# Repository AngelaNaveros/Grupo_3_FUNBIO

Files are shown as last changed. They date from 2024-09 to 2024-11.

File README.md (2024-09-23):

# FUNDAMENTOS DE BIODISENO GRUPO 3

## Descripción del curso 
> Este curso nos enseña a aplicar principios de diseño, biología e ingeniería para desarrollar **soluciones innovadoras** a problemas clínicos. Utilizando un enfoque de aprendizaje basado en proyectos, trabajaremos en **equipos** multidisciplinarios para identificar **necesidades clínicas no satisfechas**, generar ideas y crear prototipos rápidos que puedan validarse en entornos reales. A través de la **investigación de campo, el prototipado iterativo y la retroalimentación de expertos,**  adquiriremos habilidades en innovación en salud, pensamiento de diseño y validación de productos.
>
## Miembros del equipo 3

* ### **Angela Naveros Diaz**
> <p align="center" >
>
> Estudiante de Ingeniería Biomédica. Cursando 4 Ciclo. Planeo especializarme en Ing. Clínica y realizar investigaciones para apoyar al entorno con inovaciones en dispositivos médicos o facilitando el trabajo del mismo entorno.
>
> ### **Rol: Coordinador general**
> Me encargo de promover la colaboración y motivar al equipo para que se cumplan los objetivos planteados, además me encargo de subir el material al portal de GitHub.
  
* ### **Astrid Mejía Barreto**
> <p align="center" >
>
> Alumna de Ingeniería Biomédica con interés en Señales e Imágenes y Tejidos y biomateriales 
>
> ### **Rol: Coordinador de Diseño 3D** 
> Encargada de bocetar el diseño del prototipo en diferentes perspectivas y modelar digitalmente la propuesta con un software de diseño en tres dimensiones.
  
* ### **Mael Chaupis**
> <p align="center" >                    
>
> Estudiante de la carerra de ingeniería biomédica de la Pontificia Universidad Católica del Perú y Universidad Peruana Cayetano Heredia. Estoy cursando Fundamentos de Biodiseño.
>
> ### **Rol: Diseño Electrónico**
> Estoy interesado en la rama de Biomecánica y Rehabilitación.

* ### **Alexander Huamanvilca**
> <p align="center" >       
>
> Estudiante de Ing. Biomédica y me encuentro en cuarto ciclo, decidí estudiar esta carrera por varios motivos, entre ellos, la recomendación de algunos familiares, el concepto de aplicaciones de la ingeniería en el campo de la salud, logrando llamar mi atención por completo.
>
> ### **Rol: Protootipado electrónico**
> Mi rol durante el curso es el prototipado electrónico, me encargaré de la parte electrónica, acoplándome a las necesidades del equipo, verificando también, el funcionamiento del proyecto. Aprendiendo y trabajando junto con el programador para asegurar la calidad del proyecto.

* ### **Solangel Macedo Pereira**
> <p align="center" >
> 
> Alumna de Ingenieria Biomédica en 4to ciclo con rama de interés en Ingeniería de Tejidos y Biomateriales asi como Biomecánica y Rehabilitación 
> 
> ### **Rol: Manufactura Digital**
> Responsable del uso de teconologias como modelado 3D y simulaciones para la correcta fabricación del producto

## Análisis del caso
> 
> ### Caso Clínico
> La paciente es una mujer de 45 años. Sus sintomas iniciales fueron sensaciones anormales como hormigueo (parestesias) y pérdida de la función muscular. Fue diagnosticada en el año 2023 de NMO (Neumoremieltisis óptica), una enfermedad autoinminetarai que causa daño en el nervio óptico y la médula espinal a tráves de inflamación.De acuerdo a su examen físico, presenta sensibilidad hasta el ombligo, en los miembros inferiores tiene hipoestesia e hipoalgesia, en si no puede realizar marcha. Aunque presenta movimiento voluntario en los tobillos no vence la gravedad. Asimismo presenta complicaciones, úlcera por presión en la región sacra de 3X2 cm de grado III como el uso de pañal y sonda permanente. 

> ### Definición
> Las lesiones de médula espinal (LME), como su nombre lo indica, se refieren al daño causado en la médula espinal [1]; zona importante debido a su rol como medio de transporte de comunicación entre el cerebro con el cuerpo. Esta divido en 5 segmentos: cervical, torácico, lumbar, sacro y nervio coccígeas. Cada segmento se encarga de transmitir información específica como función motora o sensorial. Debido a esto, una lesión en esta zona llega a ser perjudicial para el paciente [2]. 

> ### Causas
> De acuerdo a la Organización Mundial de la Salud (OMS), cada año entre 250 500 y 500 000 personas son diagnosticadas de lesión medular. La causa más frecuente por las lesiones son traumatismo como caídas o accidentes de tránsito [1] aunque también existen lesiones no traumáticas causadas por enfermedades autoinmunes, trastornos genéticos, entre otros [3]. 

> ### Tipos
> Para determinar el tipo de lesión medular, clasificarlo de acuerdo al nivel neurológico y el alcanze de la lesión, se utiliza la escala de puntuación ASIA (American Spinal Injury Association), empleado globalmente.
> <p align="center" >
> 
> Figura 1: Escala ASIA [2]
> 
> De esta manera se realizan exámenes para identificar el nivel sensorial y función motora a través de diferentes ejercicios y pruebas; asi determinar si la lesión es incompleta (ASIA B, ASIA C, ASIA D Y ASIA E) cuando todavía existen funciones motoras y sensoriales en la región sacra, específicamente S4-S5; o completa (ASIA A), pérdida de esas funciones. [1], [2]. 

> ### Consecuencias
> Por otro lado, este tipo de lesiones causan cambios drásticos en la vida de los pacientes. Aparte de su reducida función motora y sensorial de acuerdo a la gravedad, sufren de complicaciones por su lesión. Llegan a sufrifr de una función vesical alterada, conocido como vejiga neurogénica debido al daño nervioso, el sintoma mas comun es la incontinencia. Por otro lado, las heridas por presión en la piel presentan otro riesgo más debido a la imposibilidad de realizar cambios de posición. Se estima que el 85% de pacientes con lesión medular han presentado alguna vez lesiones de presión, por ejemplo: UPP (úlceras por presión). Todas estas dificultades afectan las actividades diarias de los pacientes, poniendo en peligro su calidad de vida como su rol en la sociedad. [4]

>
> ### Tratamiento
> Es por ello la importancia de la rehabilitación cuyo objetivo es el retorno a una vida independiente y completa. Se necesita un equipo de profesionales especializados para el tratamiento en conjunto como también la participación del paciente. Freeman y Bender-Burnett [4] determinaron los siguientes cambios para cumplir la meta de recuperación.
> * Ajuste psicológico y social: Apoyo psicológico al paciente para aceptar su pérdida y nuevo rol en la sociedad.
> * Ajuste vocacional y profesional: Resulta no posible regresar al trabajo antes de la lesión por lo que se necesita cambio y adaptación0.
> * Independencia funcional: Adquisición de habilidades físicas para el cuidado personal y movilización propia en casa y afuera.
> * Adquisición de equipos médicos: Necesarios para mantener la salud del paciente así como mejorar su independencia.
> * Salud y bienestar: Seguimiento continuo para evitar secuelas secundarias como heridas por presión o infecciones.
> El enfoque es en la autonomía del paciente para que conozca las propias habilidades de su propio cuerpo, información de su lesión y confianza en si mismo. Así, se siente motivado a continuar su programa de rehabilitación y tomar iniciativa en su mejora.

> ### Contexto Nacional
>De acuerdo con datos del  INNEI [5] , 3 millones 51 mil 612 peruanos padecen de discapacidad, entre ellos, el 15%, 462 mil 062 tienen dificultad para moverse o caminar.
> Por otro lado, se tiene que tomar en cuenta el contexto socioeconómico y como este afecta en el tratamiento y rehabilitación en el paciente. En países desarrollados, existe el acceso a tecnologías, como terapias genéticas y técnicas de bioingeniería, que dan mejores resultados a comparación de países de Latinoamérica y el Caribe.
> En el Perú, no es solo el problema de la falta de tecnología sino también estructural, específicamente en el sistema de salud. La falta de organización y barreras politicas han impedido el acceso de recursos y centros de salud. Esto se ve en la mayor frecuencia de lesiones medulares no traumáticas causado por enfermedades autoinmunes, afecciones degenerativas, infecciones virales y bacterianas, entre otros. De acuero a un estudio en el Instituto Nacional de Rehabilitación de la cuidad del Callao, el 37.6% de las personas con ese tipo de lesión tenían una enfermedad infecciosa mientras que el 15.7% fueron por enfermedades degenerativas [3].
> Se necesita de una mejora del sistema actual de salud, enfocados en medidas preventivas con el objetivo de reducción de enfermedades que afectan el sistema neurológico y de esa manera se evita que progresen a lesiones de médula no traumáticas.

> <p align="center" >

## Diagrama de Ishikawa

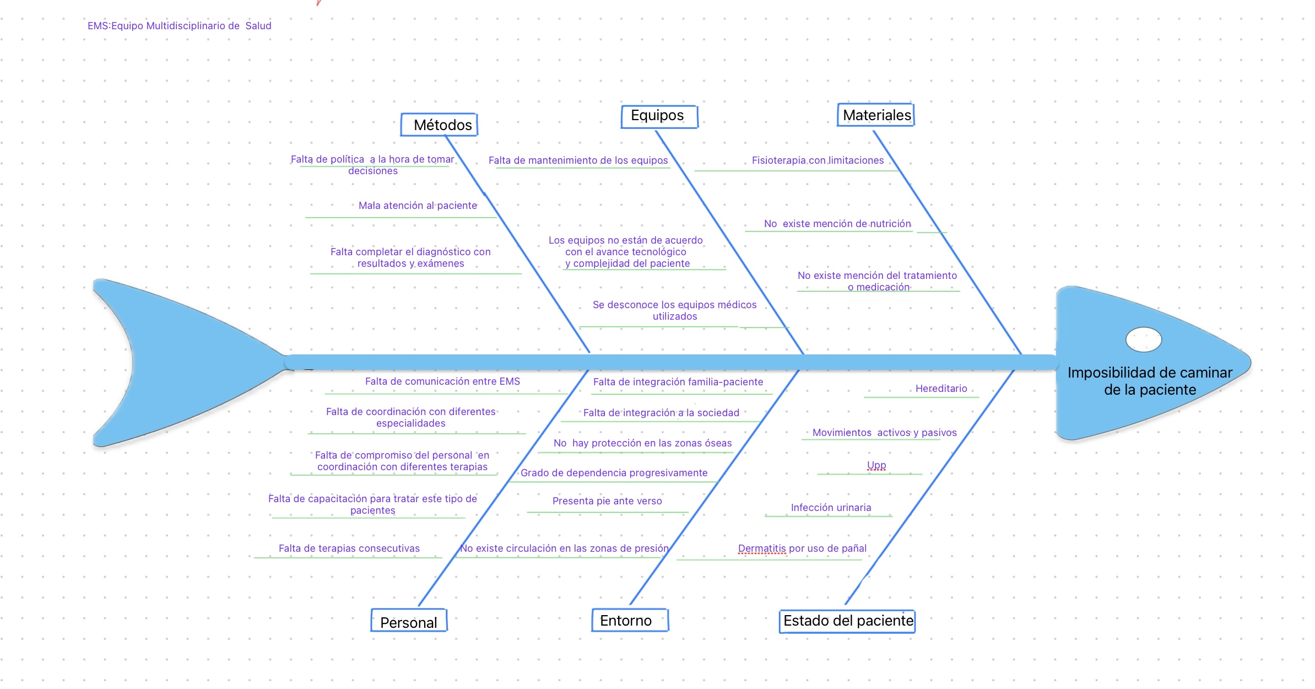
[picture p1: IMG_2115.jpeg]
> <p align="center" >

## Estado del arte
### Papers científicos
>
>  * #### Improving Walking Autonomy of People with Paraplegia wearing Powered Exoskeletons
>   Este estudio enfocado en la paraplejía, se propone el uso de exoesqueletos motorizados con un patrón de marcha que utiliza una postura inclinada para mover eficazmente el CoM hacia adelante en beneficio de la autonomía de las personas. Esta idea se dio tratando de aprovechar la diferencia de altura entre la pierna que queda delante al caminar y la que queda atrás. Presentan que los pacientes tienen dificultades para controlar el centro de masa (CoM) de su cuerpo debido a la falta de movimiento en las piernas o la cintura. Estos exoesqueletos motorizados, que son dispositivos de asistencia para las extremidades inferiores, han sido desarrollados para ayudarles a caminar nuevamente, pero tienen grados de libertad limitados y no pueden controlar completamente el CoM sin la ayuda de terapeutas físicos.
> <p align="center" > 

> * #### OMNIBOT: Un sistema de movilidad verticalizada robótica para personas con discapacidad
>   En el artículo se analiza dispositivos para que los pacientes puedan pasar de una forma sentada a una erguida, detallando las diferencias entre dispositivos de rehabilitación y dispositivos de movimiento. Proponen al dispositivo OMNIBOT el cual permite un movimiento lateral y rotacional gracias a sus ruedas Mechanum, y facilita la transición entre posiciones sentada y erguida. Este dispositivo incluye tecnología de aprendizaje automático, monitoreo biométrico, y opciones de personalización. Es adecuado para espacios interiores estrechos y no puede superar obstáculos o escaleras sin una rampa. Además señalan que existe una competencia que es TEK RMD, pero este tiene limitaciones en maniobrabilidad en espacios reducidos y accesibilidad debido a su tamaño.
> <p align="center" >
  
>  * #### Cognitive-Chair: AI based advanced Brain Sensing Wheelchair for Paraplegic/Quadriplegic people">
>
>    Este artículo presenta un sistema para el control de sillas de ruedas mediante una banda colocada en la cabeza del paciente, que utiliza señales neuronales o ondas cerebrales mediante tecnologías como ***Interfaces Cerebro-Computadora (BCI), Electrooculografía (EOG) y Electroencefalografía (EEG)***. Este sistema incorpora características de seguridad y movilidad inteligente. Además incluye funciones avanzadas como detección de caídas, capacidad para atravesar espacios estrechos y conducción autónoma. Al aplicar estas tecnologías a un modelo pequeño de silla de ruedas, se logró una precisión notable en la detección de señales neuronales. 
> <p align="center" >
>
### Ensayos clínicos

>  * #### El diseño de un ensayo de control aleatorio de caminar asistido por exoesqueleto en el hogar y la comunidad sobre la calidad de vida en personas con lesión crónica de la médula espinal
>   Ensayo clínico de dos grupos, no ciego, aleatorizado y controlado. El grupo de intervención consiste en el estándar de atención más la caminata asistida por exoesqueleto
El grupo control consiste en el estándar de atención, esto se define como el uso de una silla de ruedas para la movilidad.
El estudio tiene tres fases: Detección, orientación o formación e intervención 
Los veteranos masculinos o femeninos o el personal militar en servicio activo con SCI traumático o no traumático de duración de ≥6 meses, que tienen ≥18 años de edad, médicamente estables y usan una silla de ruedas para la movilidad en interiores y exteriores, son elegibles para la detección
La inscripción objetivo es de 160 participantes que serán aleatorizados y asignados al grupo de intervención (n = 80) o al grupo de control (n = 80)
Los resultados obtenidos durante este estudio se traducirán rápidamente a la atención clínica. El objetivo a largo plazo es compartir los datos de este estudio con el personal clínico para informar los procedimientos de capacitación y el desarrollo de pautas para la prescripción clínica del dispositivo EAW para uso en el hogar/comunitario en veteranos con SCI. Esto está sucediendo actualmente a través de interacciones continuas entre el personal de investigación y clínico.

>  * #### Apósitos de espuma multicapa adhesivo de silicona para prevenir úlceras por presión sacro adquiridas en el hospital: una evaluación económica basada en un ensayo controlado aleatorio pragmático financiado con fondos públicos vinculado a datos del mundo real
>   Tiene como objetivo estimar la rentabilidad de los apósitos de espuma de silicona multicapa sacro como terapia profiláctica adyuvante en comparación con la prevención estándar de las UPP
El grupo aleatorio es de 1633 pacientes (edad media 80 ± 12 años, el 57,6 % de las mujeres) de los cuales 1601 con intención de tratar compararon UPP en el sacro. 
El grupo de tratamiento con los apósitos multicapa de silicona (n=1062) y grupo de atención estándar (n=539)
Se observaron úlceras por presión en el sacro en el 2,8 % (30/1062, IC del 95 % 1,8-3,8 %) y el 4,8 % (26/539, IC del 95 % 3,0-6,6%) de los pacientes del grupo de tratamiento y grupo de atención estándar. El riesgo de desarrollar una nueva úlcera por presión en el sacro se redujo estadísticamente significativamente en un 41 % en el grupo de tratamiento
Conclusión: El uso preventivo de apósitos de espuma multicapa adhesiva de silicona en el sacro para una población similar a la población de ensayo pragmático puede ser apoyado tanto desde un punto de vista clínico como económico.

## Bibliografia

[1]    Actualización sobre la situación de la lesión medular en América Latina: retos y oportunidades en su atención        | Revista Colombiana de Medicina Física y Rehabilitación. (s. f.). https://revistacmfr.org/index.php/rcmfr/article/view/360/414#content/citation_reference_3 

[2]    Patek, M., & Stewart, M. (2023). Spinal cord injury. Anaesthesia & Intensive Care Medicine, 24(7), 406–411. https://doi.org/10.1016/j.mpaic.2023.04.006 

[3]    Almubaslat, F., Sanchez-Boluarte, S. S., & Diaz, M. M. (2023). A review of neurological health disparities in Peru. Frontiers in Public Health, 11, 1210238. https://doi.org/10.3389/fpubh.2023.1210238 

[4]    Somers, M., & Bender-Burnett, J. (2024). Spinal cord injury: Functional rehabilitation. F.A. Davis.

[5]    Censos Nacionales 2017: XII de Población, VII de Vivienda y III de Comunidades Indígenas. (n.d.). https://www.inei.gob.pe/media/MenuRecursivo/publicaciones_digitales/Est/Lib1539/libro.pdf 

[6]  Acta neurológica colombiana.  vol.39 no.1 Bogotá Jan./Mar. 2023  Epub Apr 05, 2023
“Evolución clínica en neuromielitis óptica comparando el manejo con azatioprina o rituximab”
http://www.scielo.org.co/scielo.php?script=sci_arttext&pid=S0120-87482023000100006&lang=es

[7] Granados Carrera, J. C. (2020). Efecto de la rehabilitación en la calidad de vida de personas con lesión medular. Anales de la Facultad de Medicina (Lima, Peru : 1990), 81(1), 6–13. https://doi.org/10.15381/anales.v81i1.16852

[8] Zeca Sanca, B., Coll Costa, J. de L., Rodríguez García, A. R., Sentmanat Belison, A., & Ramos Quian, Y. (2023). Impacto de los ejercicios físicos en la rehabilitación de pacientes con lesiones medulares cervical incompleta, en Guinea-Bissau. Podium, 18(1). http://scielo.sld.cu/scielo.php?pid=S1996-24522023000100007&script=sci_arttext

[9] Angustias, T. A. M. (s. f.). Medidas preventivas para evitar complicaciones de salud derivadas del uso de sondajes vesicales en pacientes lesionados medulares. https://scielo.isciii.es/scielo.php?pid=S1695-61412013000200018&script=sci_arttext

[10] Paulina, S. B., Tomás, G. L., Sara, V. T., Isabella, T. C., Natalia, R. V., Restrepo, C. A., Zuluaga, M., I., Paulina, S. B., Tomás, G. L., Sara, V. T., Isabella, T. C., Natalia, R. V., Restrepo, C. A., & Zuluaga, M., I. (s. f.). Evolución clínica en neuromielitis óptica comparando el manejo con azatioprina o rituximab. www.scielo.org.co. https://doi.org/10.22379/24224022436

* ##### **THX Valeria Ccoa**

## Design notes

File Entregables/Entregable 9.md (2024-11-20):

# Verificación de Diseño (Software)
<p align="center">

# Verificación de Diseño (Hadware)
> ## Preguntas clave
> * **¿Cuanto es el tiempo que debe durar la batería de forma autónoma?**
>
>     La batería debería ser capaz de durar una semana completa, día y noche, mínimo. Sin embargo, para el prototipado, buscamos que dure un lapso de 3h mínimo, para demostrar la eficiencia en la rotación del colchón.
> 
> * **¿El dispositivo es independiente?**
>
>     Por el momento la energía del circuito depende de la conexión del arduino con la computadora, sin embargo se está trabajando en la conexión con la batería.
>   
> * **¿El peso del dispositivo no supera los 5 kg?**
>
>     Se busca que la caja con todos los componentes sea lo más liviana posible para que sea de fácil transporte. Esto se puede lograr con la mejora continua de cada componente, luego de evaluado el sistema integro del sistema.
>   
> * **¿Cuántos botones físicos debe tener el dispositivo para su funcionamiento?**
>
>     Solo sería necesario de un botón fisico, para encendido y apagado del circuito.
>   
> * **¿El dispositivo es cómodo para el paciente?**
>
>     Lo único que tiene contacto con el paciente es el colchón, el cúal será elaborado con silicona genérica para el prototipo, con idea de cambiar este por el material de lona inflable.
>   
> * **¿Cuál es la inclinación necesaria que debe realizar el colchón para que el paciente pueda realizar la rotación lateral sin esfuerzo?**
>
>     La inclinación depende de la masa del paciente, pero en términos generales se recomienda una inclinación mayor a 30°.
>
>  <p align="center">

# Verificacion de Diseño (Diseño de 3D)
<p align="center">

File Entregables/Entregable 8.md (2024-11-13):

# Integración Hadware - Software - Manufactura Digital

## Introducción y Contextualización del Prototipo
> El prototipo consiste en un dispositivo cuya funcionalidad sirve de asistencia a la hora de realizar cambios posturales, a través de un sistema neumático y electrónico, y de esta manera prevenir la aparición de UPP (Ulceras por presión). De acuerdo a un estudio del Hospital de Lima [1], de 256 pacientes hospitalizados el 19,5% presento UPP en su estadía  siendo la zona más afectada la zona sacra (76%). Las UPP resultan un problema común en pacientes inmovilizados, especialmente con lesiones medulares. La falta de movimiento genera presión constante en áreas vulnerables, como oseas, zona sacra y talones, por lo que el personal de salud tiene que realizar cambios posturales cada 2 a 3 horas. Sin embargo la falta de recurso económicos y personal afecta el cuidado y tratamiento en la rehabilitación de los pacientes. Por lo que el prototipo brinda la solución con el problema de recursos sino que también ofrece la oportunidad de autonomía al paciente ya que el dispositivo le dara la capacidad de ser un participante activo en su tratamiento, este será capaza de realizar los cambios posturales por su cuenta gracias al apoyo que el prototipo brinda.  
>
> Para la fase de integración al armado del prototipo se espera que el sistemático neumatico y electronico funcionen correctamente por separado así mismo en la hora de unión de estos para el inflado y desinflado a control del colchón. 
>

## Componentes del Prototipo
> * **Lista de componentes principales:**
>    - Válvulas de 4 entradas: 
>    - Válvulas para servomotor:
>    - Tubos de latex de 6mm de diametro interior:
> * **Interacción entre componentes:**
>
>     La **válvula de 4 entradas** se conecta a la máquina de llenado al vacío mediante los **tubos de látex**, con un pedazo de estos tubos conectado a la máquina que luego convergen en 3 sistemas diferentes donde conectan a las **válvulas para servomotor** para inflar de forma independiente cada sector del colchón. En estas válvulas para servomotor, se coloca una manguera para llenado, que es la que continua desde la máquina de llenado al vacío y la otra manguera que se une del colchón y tiene salida al exterior, para permitir que el colchón se desinfle.
>   
> * **Diagrama de integración:**
><p align="center">

## Proceso de Integración
> * **Plan de Integración**
>    Como requerimos que las válvulas dejen o no, pasar el aire hacia los cojines. Implementaremos servo motores para negar y aceptar el pase del aire, luego aquello que de las órdenes será un módulo bluetooth  para mandar las señales hacia un microprocesador. En este caso este microprocesador será Arduino UNO, es mediante su programación que haremos que nuestro sistema funcione. Para unir los componentes necesitaremos un protoboard y cables jumper.
>
> * **Pruebas Intermedias:**
>  1. Primero es necesario conocer las conexiones y verificar si funcionan con el arduino UNO.
>     <p align="center">
>  2. Después de entender cómo funcionan los servos , verificaremos la disponibilidad y uso del módulo bluetooth.
>     <p align="center">
>  3. Finalmente, después de lograr entablar una relación entre el módulo bluetooth y los servos, los integramos físicamente en un mismo sistema(Integramos solo un servo en la imagen para garantizar un primer uso eficiente).
>     <p align="center">

> * **Objetivos Específicos:**
>    - La idea es poder dar órdenes de movimiento a los servomotores mediante comandos o una aplicación externa conectada al módulo bluetooth, obviamente todo ello controlado mediante programación Arduino.
>      
> * **Desafíos y ajustes realizados:**
>   - Problemas encontrados:
>       * Al inicio del modulo bluetooth pasaba el primer paso con *“Verify”* pero cuando tocaba  probar el *upload* mandaba mensajes de error. No reconocía al módulo. Sin embargo, luego de probar de diferentes formas el código, desconectando los pines de transmisión de datos y recepcionando datos(TXD Y RXD) y dandole inciar al “veriffy”  y seguido el “upload”. Una vez funcionó sin conectar los pines. Se definieron nuevos pines para que cumplan las funciones de TXD Y RXD(eran normalmente 0 y 1, pero se cambiaron por 2 y 3).
>
>       <p align="center">
>       Mi resultado fue que termino por funcionar con un codigo diferente  y no me figuraba ningun mensaje de error.
> <p align="center">
>        
>         Se decidió probar el Serial monitor con la app de mi celular “ Arduino bluetooth controller”
> <p align="center">
>        
>         El servo uno responde a lo siguiente: realiza un giro de 180 grados en sentido antihorario  cuando sale la letra “a”, y da un giro (con el mismo angulo) pero en sentido horario al momento de  salir la letra  “j” (esto es para un solo servo).
><p align="center">
>
> 
> * **Revisión de compatibilidad y sincronización:**
>  
> (esto es ya comprobando los 3 servos)
>
>  mando el mensaje desde mi celular 
><p align="center">
> 
> para este caso definimos lo siguiente:
> 
> - servo 1 :giro 180 grados  sentido antihorario  al recibir la señal de la  letra “a” y sentido  horario  con el mismo giro para la letra  “j”
> 
> - servo 2: giro antihorario(180 grados ) con la letra “s” y  giro horario (mismo 180 °) con la letra “k”
> 
> - servo 3 : giro antihorario(180 °) con la letra “d” y giro horario ( mismo  180°) con la letra “l” y lo recibi y figura en mi serial monitor del codigo arduino 
><p align="center">

## Pruebas y Verificación
>
> 1. Primero necesitamos verificar que los servomotores funcionen de manera alterna para así verificar su funcionamiento. Para verificar las conexiones y su funcionamiento , utilizaremos tanto el IDE Arduino y Tinkercad para comprobar que funcionen correctamente bajo código.
> <p align="center">
>
> 2. Ahora verificaremos que el módulo bluetooth funcione correctamente y nos bote señal y  de esa manera verificar que los servos nos reciban las órdenes..
>
> <p align="center">
> 
> * **Resultados y pruebas:**
>   - La idea de las pruebas era verificar que el circuito sea un mismo sistema y que cada componente esté relacionado al otro.
>   - Gracias a las pruebas nos dimos cuenta que era más factible un módulo bluetooth que un sensor IR, debido a la diferencia de facilidad de obtención de señal.
>   - De igual forma, gracias a las pruebas físicas nos dimos cuenta sobre limitaciones con el código en IDE Arduino, ya que únicamente con Tinkercad, no aseguraba el 100% del funcionamiento del circuito y/o sistema.
>
> * **Resultados y pruebas:**
>   -  Como bien vimos en las pruebas, el Arduino es capaz de recibir los mensajes desde un dispositivo móvil mediante el módulo bluetooth. Por lo que, gracias a esta aplicación, el enviar mensajes para activación o desactivación de los servos es factible.
>   - Como los servos son capaces de recibir las órdenes del Arduino, su movimiento será el que logre que las válvulas se abran o se cierren, lo que permitiría el funcionamiento de la misión principal.

## Conclusiones y Próximos Pasos
> * **Resumen de logros:**
>   - Se logró la aprobación del circuito electrónico, garantizando su funcionamiento bajo las condiciones de operación establecidas. Se han culminado exitosamente las pruebas del mecanismo.
>   - Se aprobaron las ediciones finales en el modelado 3D y se pasa a llenar la solicitud de impresión 3D en el laboratorio físico.
>   - Por el momento, se buscan alternativas de fabricación para el colchón, teniendo como opciones la impresion en negativo y utilizar silicona o fabricarlo con material de lona inflable). En el transcurso de la semana se realizarán pruebas de fabricación que posteriormente serán enviadas para la debida aprobación y continuando con su fabricación.
>   - Una vez se tengan impresas las piezas de prueba y el colchón fabricado, se realizarán las debidas pruebas, integrando el mecanismo con la manufactura 3D para ver el correcto funcionamiento del prototipo.
> * **Aspectos por mejorar:**
>   - La falta de pruebas en las mangueras neumáticas junto con las piezas de impresión 3D presentan un riesgo para el cumplimiento de los plazos de entrega. Cualquier ajuste al modelado 3D podría generar retrasos significativos
persiste el problema de los métodos de fabricación para el colchón.
>   - Aún no se tiene un método establecido para la fabricación del colchón, por lo que se realizarán pruebas durante el transcurso de la semana para determinar un método de fabricación junto a los asesores. Esto resultaría en una complicación debido al tiempo restante.
> * **Siguientes fases del desarrollo:**
>   - Próximamente se implementarán las pruebas debidas para la manufactura 3D con el circuito eléctrico sin utilizar el colchón. Con el objetivo de ver si las válvulas impresas en 3D tienen un buen funcionamiento y se adaptan al sistema. De observar una mala adaptación, se podrán realizar los ajustes necesarios para que sean enviados a la debida aprobación y se pueda solucionar en el menor tiempo posible.
>   - Con el objetivo de seleccionar la tecnología de fabricación más adecuada, se procederá a evaluar las propuestas de impresión negativa en silicona y de lona inflable. Se realizarán pruebas piloto para cada método de fabricación y se evaluará la factibilidad de ambas para dar paso a la fabricación de una opción.
## **Bibliografía**
> 
> [1] M.V. Godoy Galindo, B. Huamaní Flores, y Y. Musayón Oblitas, “Prevalencia de úlceras por presión en pacientes hospitalizados de un hospital de Lima” Enferm. Herediana, Vol. 13, pp. 20-27, Junio 2020 https://revistas.upch.edu.pe/index.php/RENH/article/view/4146/4683

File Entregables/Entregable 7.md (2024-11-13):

# Hadware electrónico   
>
> * Easy EDA (Diseño esquemático de circuito):
> <p align="center">
>
> * Avance de prototipado electronico:
>
>  Segunda prueba
> <p align="center">
> <p align="center">
> <p align="center">

# Software
>
>  * Diagrama de flujo
> <p align="center">
> <p align="center">

# Impresion 3D
>
> * Colchón 3D
> <p align="center">
>
> * Valvula triple entrada
> <p align="center">
> <p align="center">
>
> * Valvula cuatro entradas
> <p align="center">
> <p align="center">
>
>  * Válvula Microservo
> <p align="center">
> <p align="center">
> <p align="center">
>
> Link del Onshape: https://cad.onshape.com/documents/ae2ef44f2d8c1977eb63c756/w/e91bbc834956a6f8ca445963/e/79384267cc61f8b46981e7fe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 

> Retos y limitaciones:
> * El codigo Arduino por comando Bluetooth aún no corre como se espera, ya que fue cambiado recientemente de IR al módulo HC-05.
> * Falta integrar la función de los servos con las válvulas y el colchón para comprobar eficacia.
> * Avanzar con la creación y prototipado del colchón de forma simple para poner a prueba el sistema de servomotores de forma correcta.

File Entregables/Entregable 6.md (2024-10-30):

# Iteración por bloques
## Hadware Electrónico:
> * Easy EDA (Diseño esquemático de circuito):
> <p align="center">

> * Codigo Arduino:
> <p align="center">
> <p align="center">
> <p align="center">
>   
> * Avance de prototipado electronico:
> <p align="center">
> 
## Software:
> <p align="center">

## Impresión 3D:
> <p align="center">
> <p align="center">
>
> * Soporte Válvula cuatro entradas
>   
> <p align="center">
>
>  * Soporte Arduino
> <p align="center">
>
>  * Soporte Batería 
> <p align="center">
>
>  * Soporte Microservo
> <p align="center">
>
>  * Corte Láser
> <p align="center"> 
> Link del Onshape: https://cad.onshape.com/documents/ae2ef44f2d8c1977eb63c756/w/e91bbc834956a6f8ca445963/e/79384267cc61f8b46981e7fe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 
>
# Reporte de pruebas, retos y limitaciones
> * Dificultad al momento de comprar/conseguir debido al escaso mercado neumático en el país, se compran válvulas del extranjero para continuar con el proyecto.
> * Falta de tiempo al momento de la obtención de válvulas, debido a que se tendrá que cambiar le diseño de soportes según las válvulas físicas compradas, dado que no se tiene una referencia de medida.
> * Construir el colchón desde el inicio de acuerdo a la forma deseada con el material adecuado.

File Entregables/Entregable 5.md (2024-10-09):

# Diagrama o Esquema Electrónico del concepto de solución
> <p align="center">

# Modelado 3D de los componentes por separado
> * Soporte Aurduino
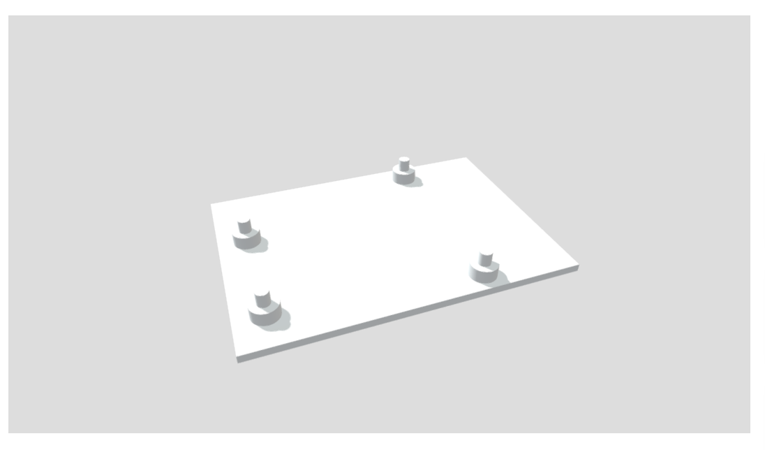
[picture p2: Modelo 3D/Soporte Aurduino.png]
>   <p align="center">
> * Soporte Batería
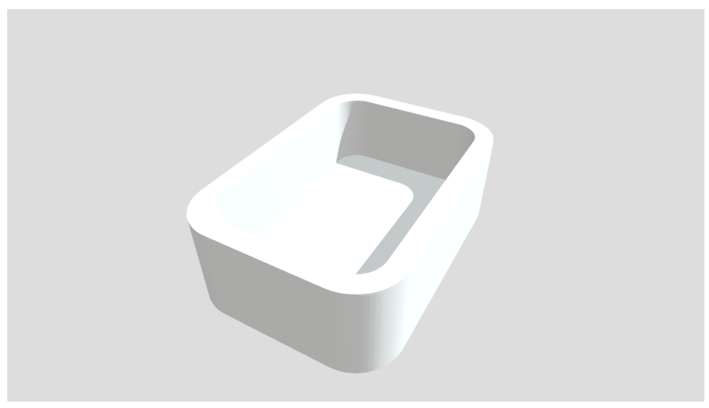
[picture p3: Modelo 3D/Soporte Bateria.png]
>   <p align="center">
> * Soporte Bluetooth
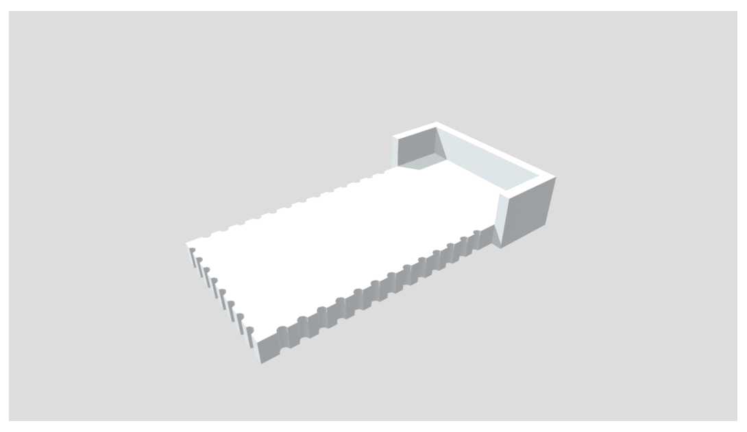
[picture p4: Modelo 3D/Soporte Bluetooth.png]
>   <p align="center">
> * Soporte IR Sensor
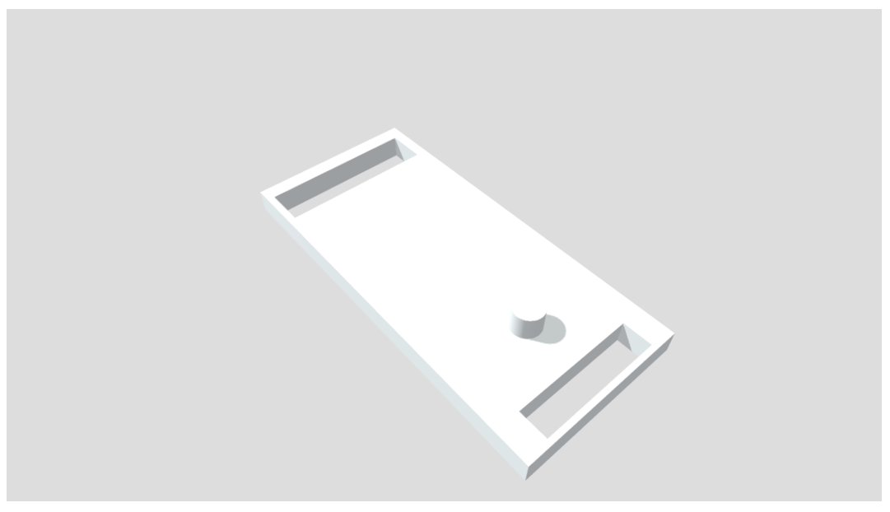
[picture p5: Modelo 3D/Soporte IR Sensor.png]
>   <p align="center">
> * Soporte Relay 4
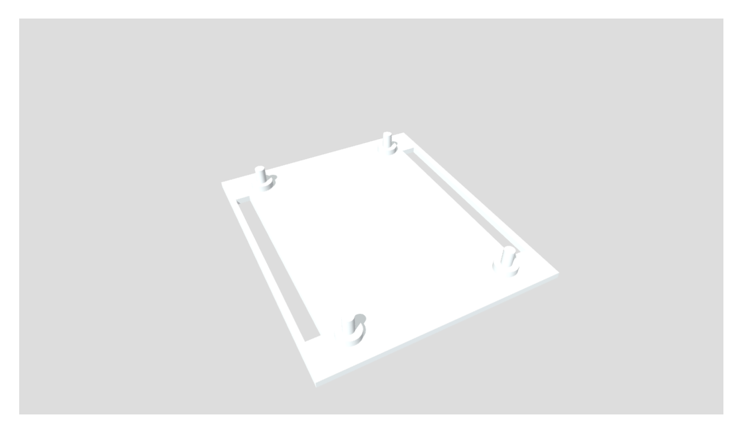
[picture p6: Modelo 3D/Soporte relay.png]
>   <p align="center">
> * Soporte sensor de sonido
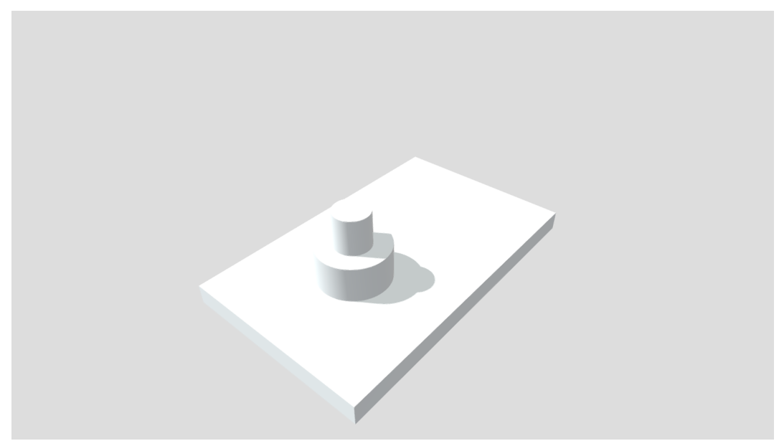
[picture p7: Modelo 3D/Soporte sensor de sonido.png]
>   <p align="center">
> * Soporte servomotor
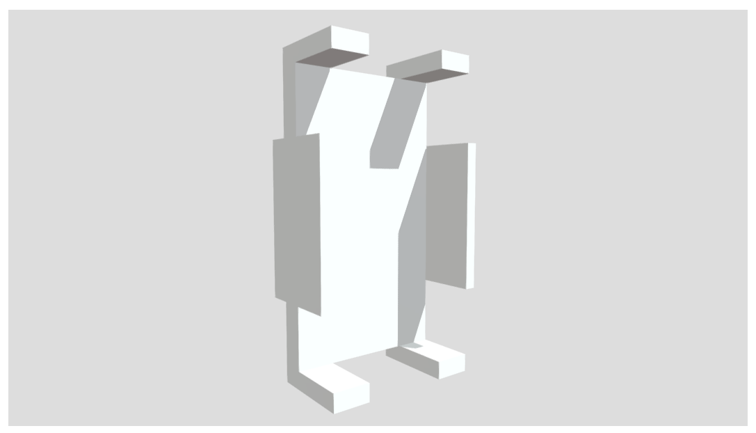
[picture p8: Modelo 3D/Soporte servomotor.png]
>   <p align="center">
> * Soporte válvula
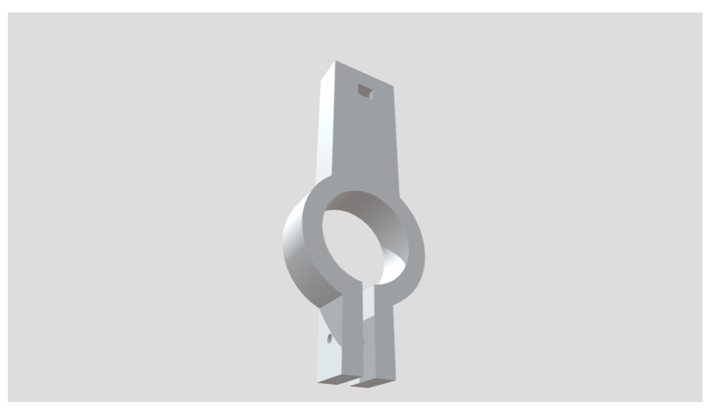
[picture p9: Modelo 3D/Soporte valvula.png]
> <p align="center">

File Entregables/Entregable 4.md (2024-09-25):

# Caja negra y esquema de funciones

> **Entradas**
> * Energía: Dispositivo con fuente en baterías en el control remoto y recargable para la parte de las abrazaderas.
> * Aire: Elemento del cual el dispositivo se basa para realizar sus funciones.
> * Comando de posturas: Control remoto de fácil entendimiento que indique el cambio postural que se desee realizar.
>   
> **Salidas**
> * Aire: Elemento residual del dispositivo
> * Rotación de paciente: Objetivo del dispositivo, realizar cambios posturales de 90 grados en ambos sentidos
>   
> **Esquema de funciones**
> <p align="center">
>
> **Funciones**
> * Reguladora de energía: Regula la energía entregada por la batería. 
> * Captar 1: Captar  el aire para inflar mediante absorción o válvulas de presión.
> * Detectar (control remoto): Recibe la señal del control remoto 
> * Procesar: Procesa la información detectada y manda el aire a los infladores indicados. 
> * Notificar: Esta función avisa a los infladores que se activen.
> * Regulador de aire: Regular el aire para los infladores
> * Accionar:  Se realiza el inflado y da el apoyo para la rotación del paciente 

# Matriz morfológica
> <p align="center">

# Tabla de valoración 
> <p align="center">

# Conclusión de concepto de solución elegido
> La propuesta número 4 fue la ganadora según la tabla de valoración, presenta una mayor facilidad al momento de usarlo por su tecnología bluetooth y tiene posibilidad de ser automático para darle mayor independencia al paciente al momento de realizar sus cambios posturales.

# Boceto
> ## **Boceto 1**
> <p align="center">
> <p align="center">
>
>  ## **Boceto 2**
> <p align="center">
> <p align="center">
>
> ## **Boceto 3**
> <p align="center">
> <p align="center">

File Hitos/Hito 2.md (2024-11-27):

# ASSMA
## Problemática
> La inmovilidad en la parte inferior de las piernas puede causar úlceras por presión debido a la falta de circulación y la presión constante sobre la piel. De acuerdo a un estudio del Hospital de Lima [1], de 256 pacientes hospitalizados el 19,5% presento UPP en su estadía siendo la zona más afectada la zona sacra (76%). Las UPPs dañan los tejidos, especialmente en áreas como talones y tobillos, aumentando el riesgo de infecciones y complicaciones. La prevención incluye cambios frecuentes de posición, el uso de superficies especiales y una buena nutrición. Si ya se presentan úlceras, es vital un tratamiento adecuado para evitar agravamientos.
> Respecto al estado del arte, se utlizaron como referencia el "Sistema de Colchón de Presión Alternante con Ajuste Automático" [2] y  los "Cojines para úlceras de cama para posicionamiento de glúteos, cojín de presión para úlceras, almohada de alivio de presión en forma de dona, cuña para posición de dormir, cuña después de cirugía" [3]
## Solución
> Dispositivo de bajo costo no invasivo que reemplaza el uso de cojínes anti escaras que además mediante la elección del usuario de rotación lateral a la derecha o izquierda, con un sistema de válvulas unidas a servomotores, se selecciona una fila de cojinas para inflar, de tal modo que la inclinación del colchón facilite la rotación del paciente con la fuerza impulsada por su tronco. Este dispositivo se ubica debajo del paciente (como un colchón cualquiera) lo cual lo hace poco invasivo y con una facilidad para retirar y colocar en el paciente.
## Tracción
> * El boceto y su modelado 3D final
>
> <p align="center">
> <p align="center">
  
> * Diagrama de flujo
> * 
> <p align="center">
> <p align="center">
  
> * Diagrama Esquemático del prototipo electrónico
> <p align="center">

> * Proceso del ensamble de la Manufactura Digital
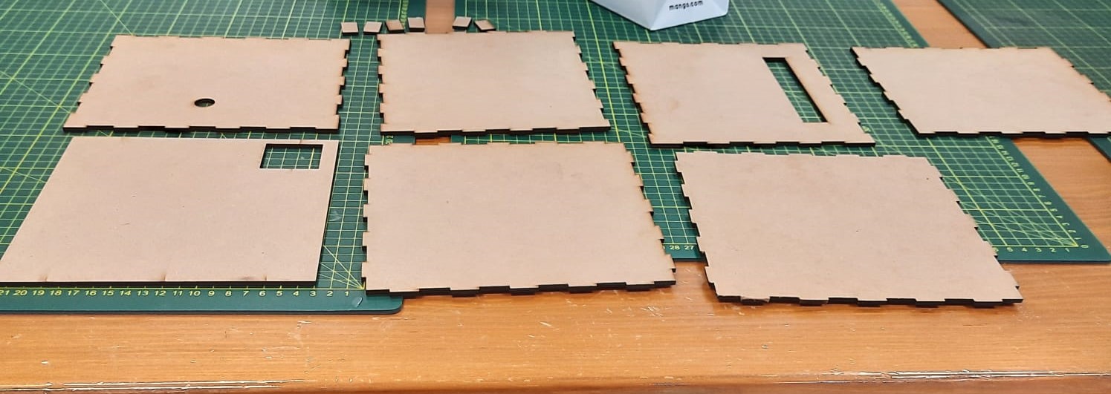
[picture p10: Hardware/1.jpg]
>   <p align="center">
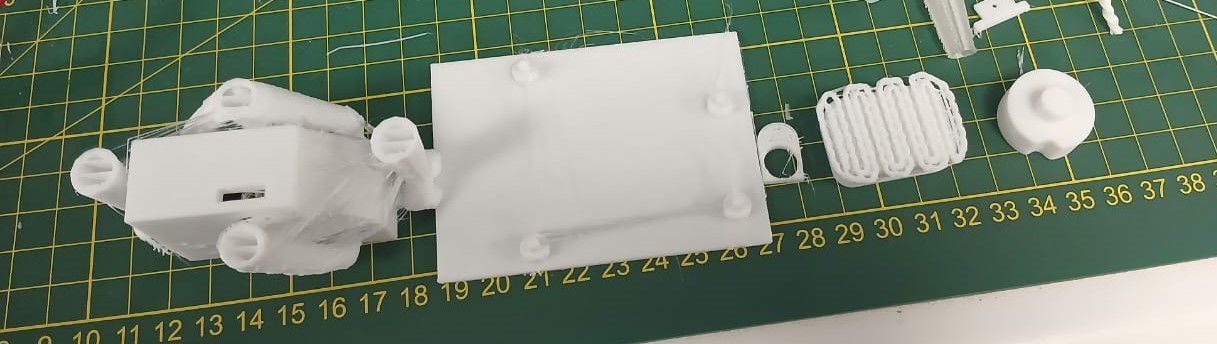
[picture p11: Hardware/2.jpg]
>   <p align="center">
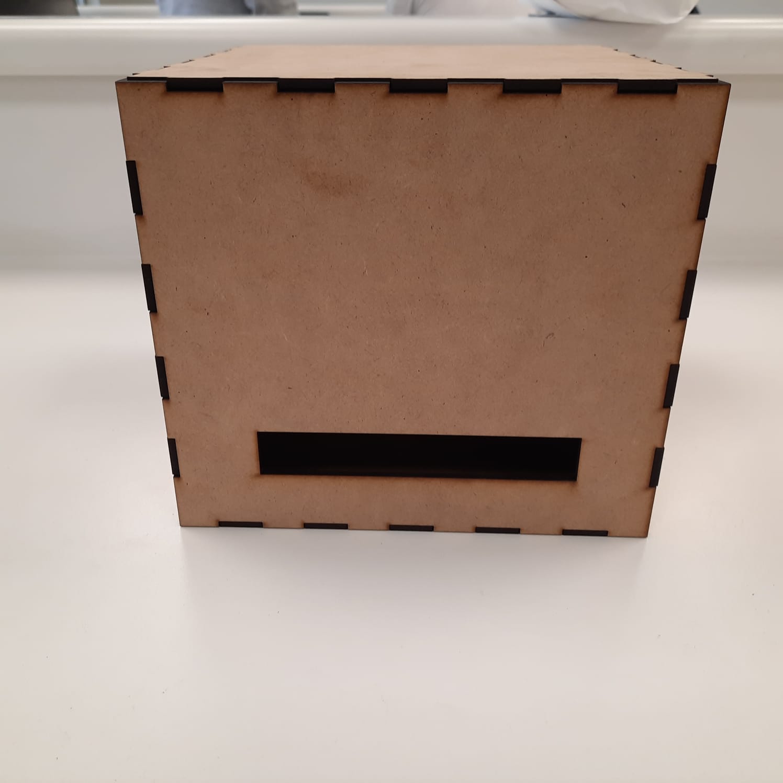
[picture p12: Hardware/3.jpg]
>   <p align="center">
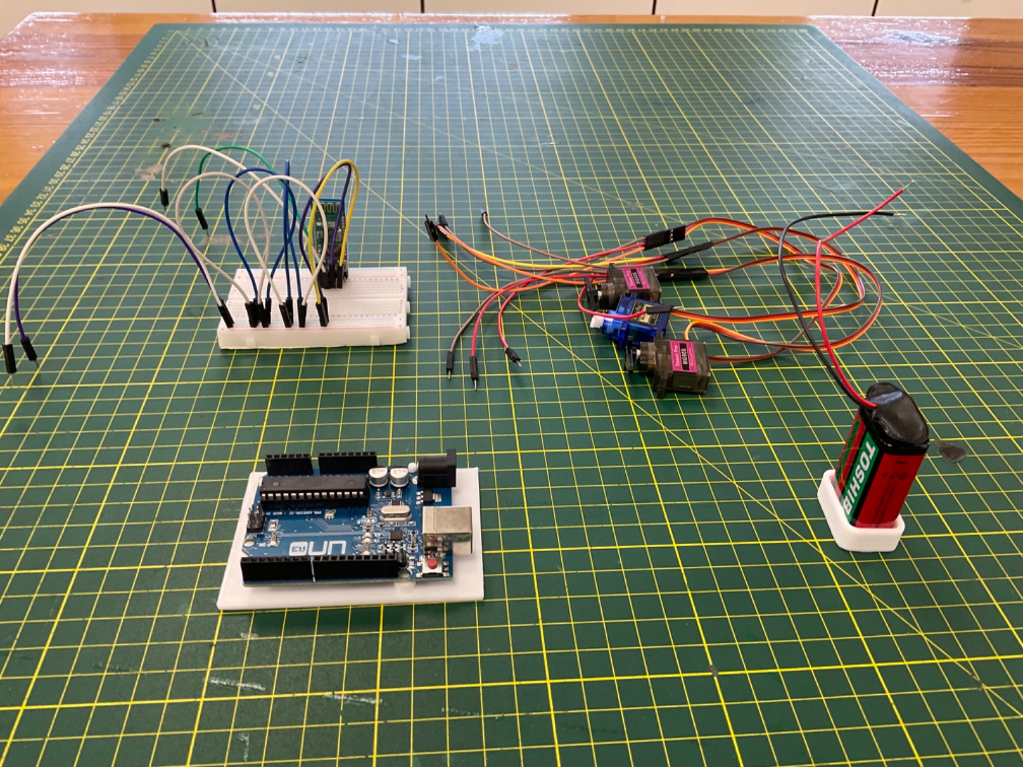
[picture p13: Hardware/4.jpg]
>   <p align="center">
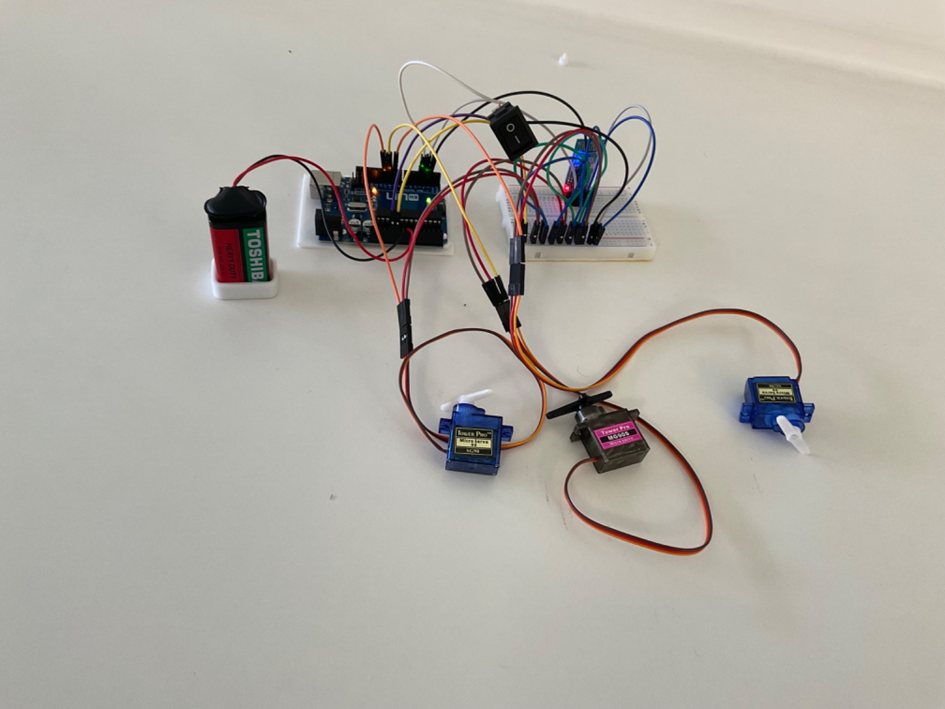
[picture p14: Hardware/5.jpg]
>   <p align="center">

> * Prototipo integrado
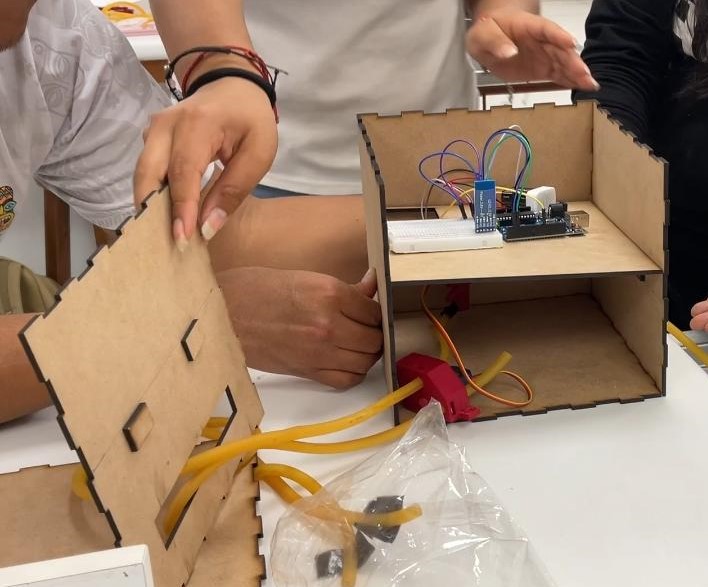
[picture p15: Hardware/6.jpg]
>   <p align="center">
>   * Resultados obtenidos:
>         * Se unieron las partes electrónicas, impresión 3D y corte láser para armar el prototipo
>         * A tráves de un “cojín” prueba, se realizo la prueba del dispositivo y el inflado del “cojín”
### Demo
> un video del prototipo de baja fidelidad funcionando según su objetivo principal
## Limitaciones
> * Demora en la impresión del model del cojín, retraso el proceso de armado del prototipo
> * Después de varias pruebas en la parte electrónica, la batería empleada no tenpia el voltaje necesario
> * Complicaciones en el reconocimiento del módulo Bluetooth
## Pruebas y testeos
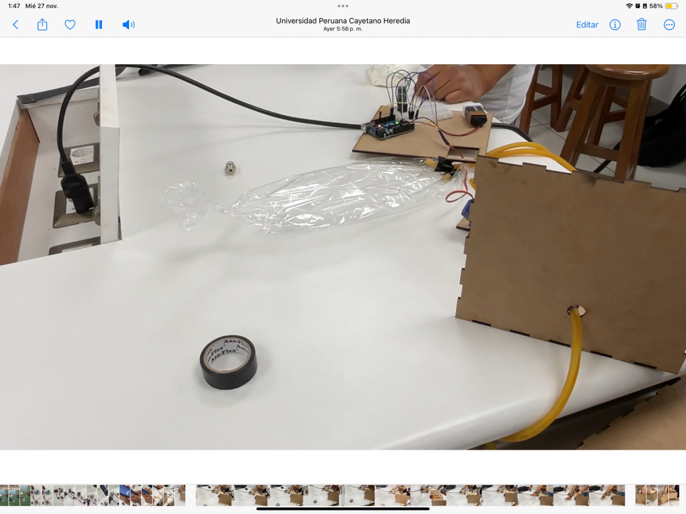
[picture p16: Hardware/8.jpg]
>   <p align="center">
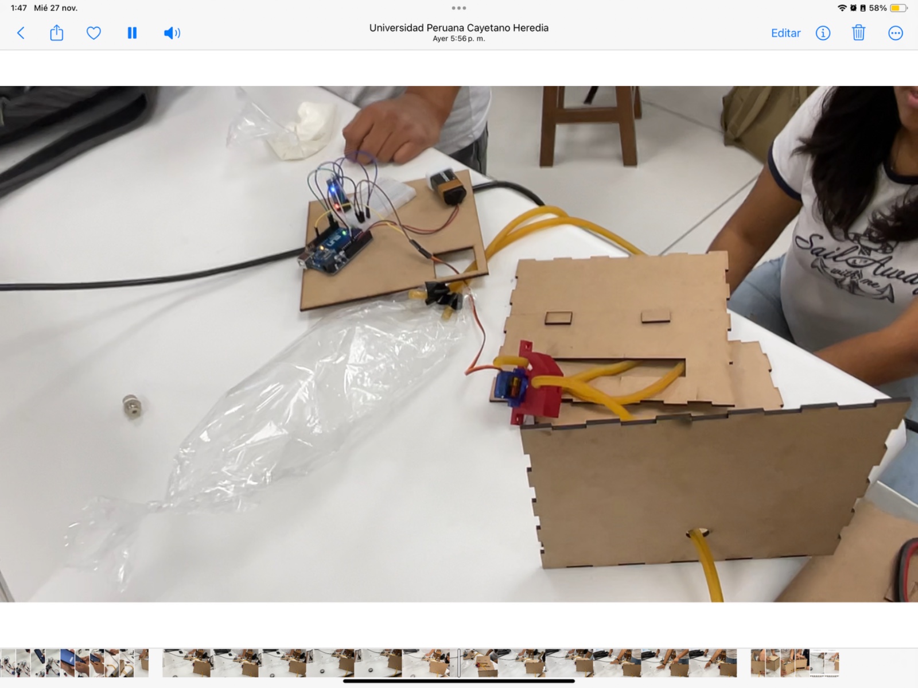
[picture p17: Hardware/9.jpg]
>   <p align="center">
## Canva
> https://www.canva.com/design/DAGXhgFEqCc/dNvT1QNXmBDkStJcOZzv0A/edit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

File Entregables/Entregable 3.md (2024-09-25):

# Problemática
> ## Contexto:
> El Hospital de Lima realizó un estudio, donde se incluyeron 256 pacientes hospitalizados, esto con la finalidad de buscar determinar la prevalencia de las úlceras por presión en dichos pacientes [1]. Se tomó a consideracion  la edad y otras características. Como resultado se identificó que la prevalencia de la upp fue del 19.5% en la población evaluada.La mayoria  eran adultos mayores y predominancia del sexo masculino. Además la zona más afectada fue la región sacra (76%). En el caso de nuestro paciente (S4 y S5). Por esto las úlceras por presión representan un problema prevalente en pacientes hospitalizados y se brindan sugerencias como implementación de programas preventivos y un monitoreo constante. Así también,es crucial enfocar los cuidados en zonas de mayor riesgo.
>
> Se hizo una guía de práctica clínica, esto para el diagnóstico y manejo de las upp.La finalidad era mejorar  la calidad de atención de los pacientes con upp [2].
> * **Se clasificaron por 4 categorias:**
>   * I)enrojecimiento de la piel
>   * II)Pérdida parcial del grosor de la piel
>   * III)Pérdida  total del grosor de la piel
>   * IV)Destrucción masiva
> * **Se consideraron factores de riesgo:**
>   * Presión prolongada
>   * Factores extrínsecos e intrínsecos
> * **Tratamiento:**
>   * Cuidados como reducción de presión sobre áreas vulnerables
>   * Eliminación del tejido necrótico
>   * Uso de antibióticos  tópicos o sistemicos
>   * Uso de apósitos que favorezcan la curación
> * **Prevención:**
>   * Cambios de posición 2h/c
>   * Uso de superficies de apoyo
>   * Higiene adecuada y control de la humedad
> * **Complicaciones:**
>   * Sepsis
>   * Infecciones locales o sistémicas
> * **Caso clínico: Paciente con neuromielitis**
>
>   ¿Cómo le   surgieron  las úlceras por presión al paciente ?
>
>   Las úlceras por presión surgieron porque el paciente no podía mover la zona lumbar (del ombligo  hacia abajo) debido a su enfermedad.Debido a su enfermedad, neuromielitis óptica,que lo condiciona a no tener  controlar  sus extremidades inferiores. Estas tienen movimientos  involuntarios.Por lo tanto,  desarrolló una postura de triple flexión. Dicha postura  en forma de triángulo  ocasionó una presión  constante  en la parte de la sacra ,lo que fue llevando a desarrollar úlceras.
> En la ingeniería biomédica ,se destaca por emplear el uso de equipos médicos enfocados en la rehabilitación de pacientes.En este caso,se está usando un equipo médico llamado “mesa ipevestadora” para  corregir su postura y estirarse.
> La ingeniería biomédica tiene relevancia para brindar equipos médicos innovadores para facilitar la condición del paciente.
> ## Definición del Problema:
> Úlceras por presión (upp). Son de grado III, no genera irrigación y existe región comprometida por la presión.
> Se llega a infectar la herida  debido a que el paciente no tiene control de esfínteres.
> Tiene dermatitis
> ## Impacto:
> Se analizan los siguientes aspectos para conocer el impacto en la vida del paciente:
> * Impacto en la calidad de vida: Las UPP están mayormente asociadas a la inmovilidad, donde la interacción de estas presiones juntos con la humedad y otros factores del paciente inducen al daño tisular, donde los tejidos blandos cerca de una prominencia ósea son dañados por la presión. Las afecciones en la piel debido a las lesiones por presión van desde eritema hasta úlceras que se extienden por el hueso causando dolor y afectando el bienestar general.[3]
> * Carga asistencial y económica: Las úlceras por presión requieren un seguimiento médico constante, dado que la prevención y el tratamiento incluye asistencia médica para la movilización del paciente en posiciones corporales específicas para redistribuir presiones. Además, las UPP son síndromes frecuentemente geriátricos que incrementan la inversión socioeconómica y sanitaria; que quintuplica la estancia hospitalaria, e incrementa la mortalidad, las complicaciones infecciosas y comorbilidades, así como los costos de tratamiento, estimando un tiempo medio de tratamiento de 116 días [4]
> * Complicaciones asociadas: Las UPP se clasifican según el daño tisular en 4 etapas, la herida se clasifica según su extensión más profunda, donde en la etapa 3 y 4 se observa tejido necrótico, tejido subcutáneo, tejido de granulación, fascia, músculo u otras estructuras subyacentes [5]

# Propuesta de solución
> ## Descripción de la Solución:
> Dispositivo que facilita al paciente realizar ajustes posturales de manera autónoma, previniendo la aparición de úlceras por presión, empleando la robótica blanda y un sistema neumático para dar soporte y reducir presiones.
> ## Características del Prototipo:
> * Sistema neumático: Este dispositivo emplea un sistema neumático en las áreas más susceptibles a la presión que simulan almohadas, estas se activan de acuerdo a la posición corporal que adopte el paciente.
> * Sensor de reconocimiento de voz: El dispositivo podrá ser activado y modulado por comando por voz, para facilitar su uso con el paciente.
> * Dispositivo acomodable: El paciente al momento de realizar el giro podrá acomodar las almohadas de giro a su gusto, se incluirá una soga de apoyo para el movimiento.
> * 

> ## Beneficios:
> * En primer lugar, la practicidad y multiuso. A comparación de productos como el “Sistema de Colchón de Presión Alternate con Ajuste Automático” [6] y/o “Cojines para úlceras” [7] que solo pueden utilizados en la camilla de hospital o silla respectivamente; nuestra propuesta combina los beneficios de ambos productos, su ergonomía.  Al ser un sistema de 5 cojines, pueden ser utilizados en las diferentes posiciones que se encuentra el paciente, resultando más conveniente acomodarlos para el personal de salud.
> * En segundo lugar, funcionalidad ampliada. No solo se enfoca en la detección de presiones en zonas específicas y alerta como en “ES2926481T3 – Métodos inalámbricos de alerta de úlceras por presión y sistemas de los mismos ” [8]; sino que también, la propuesta realiza automáticamente redistribución de presiones a tráves de un sistema neumático. Asimismo, cuenta con sensores de humedad,especificamente el en cojin para la zona del sacro, que avisan al personal de salud cuando el paciente realiza sus necesidad.
> * La propuesta de solución se enfoca en la comodidad del paciente y disminuir en todo lo posible los factores de riesgo para la aparición de úlceras de presión. 
> ## Viabilidad Técnica:
> * **Recursos:**
>     * Sensores de presión
>     * Sensores de humedad
>     * Sistema neumático
>     * Gel (glicina) para los cojines
>     * Batería
>     * Tablet o monitor
> * **Tecnología**
>   * **Software para:**
>     * Analizar los datos de los sensores de presión y humedad
>     * Aviso de zonas propensas a desarrollar Úlceras de presión
>   * **Sistema neumático**
>     * Cambio automático de distribución de presión
> * **Conocimientos**
>     * Uso de robótica blanda y materiales
>     * Programación para el interfaz intuitivo (software)
>     * Circuitos electrícos y válvulas de presión 

# Coherencia

> ## Contexto del Proyecto
> En este caso se presenta un inflable en la parte de los muslos, el cual se activa por zonas dependiendo del cambio postural que se ocupe necesario para prevenir las úlceras por presión, causadas por la falta de movimiento en las piernas. Además se realizará de forma que se practico de colocar y quitar para la higiene y cambio de ropa de la parte inferior. Nuestra idea se genera en base a que en el medio existen dispositivos parecidos pero no especializados para el cambio postural y que se realize de forma autónoma. Finalmente todo esto se producirá a bajo costo y con un sistema de fácil comprensión para el usuario.
> 
> ## Objetivos del Proyecto
> * **Generales**
>   * Se busca la prevención de úlceras por presión en la paciente mediante un dispsitivo de fácil adaptabilidad y de bajo costo.
> * **Específicos**
>   * Desarrollar un sistema que capte el momento de rotación y conecte cada fase de rotación con cada segmento del inflable más favorecedor.
>   * Encontrar recursos (sensores, sistema arduino, etc) de bajo costo para el desarrollo de equipo.
>     
> ## Justificación del Prototipo
> La propuesta de solución se basa en la utilización de inflables alrededor de las piernas para evitar el roce de las rodillas. Según los datos de un Hospital de Lima sobre la prevalencia de UPP, el 76% de las úlceras por presión ocurren en la zona sacra y los talones, donde la fricción y presión constante son factores críticos[9]. Este prototipo aborda directamente la necesidad de reducir la presión en estas áreas al mantener las piernas separadas mediante inflables y permitir una mayor movilidad con el sistema de rotación, lo que es fundamental para prevenir la formación de úlceras.
>
> Teniendo en cuenta los métodos tradicionales, que suelen depender de cambios de posición manuales y uso de cojines estáticos, este prototipo introduce una mayor flexibilidad para los cuidadores y una mayor comodidad para los pacientes, reduciendo significativamente el tiempo de exposición a presiones sostenidas, una de las principales causas de UPP según el estudio de indicadores UPP en el Hospital Hipólito Unanue[9].
>
> Además, al estar enfocado en prevenir el roce entre piernas, el dispositivo también puede ser efectivo en pacientes con incontinencia urinaria, un factor de riesgo adicional para la aparición de UPP, ya que la humedad constante macera la piel y la hace más vulnerable[9]. Esta funcionalidad del prototipo resulta ser una ventaja adicional frente a otras soluciones, que no siempre contemplan de manera afectiva este factor.

> ## Alineación del Prototipo
> La problemática principal abordada por este prototipo es la prevención de las UPP en pacientes inmovilizados, quienes enfrentan un alto riesgo de desarrollar estas lesiones debido a la presión constante sobre áreas óseas, como la zona sacra y talones, y a la fricción entre superficies dura, como las rodillas[9].
>
> El prototipo inflable resuelve directamente estos problemas al crear una barrera entre las piernas para evitar la fricción, y al mismo tiempo, permitir la rotación controlada del paciente sin requerir la intervención constante de los cuidadores.
>
> Según los indicadores UPP, la movilización frecuente es clave para reducir la incidencia de estas úlceras, especialmente en pacientes postrados o con dificultades motoras[1].
>
> Al facilitar el movimiento mediante el brazo palanca, se mejora la circulación y se disminuye la presión constante en puntos críticos, lo que contribuye a evitar la formación de UPP graves en áreas de alto riesgo, como los talones y la región sacra[9].

# Resumen
> Las úlceras por presión (UPP) representan un **problema** común en pacientes inmovilizados, como aquellos con neuromielitis óptica (NMO), que no pueden moverse ni controlar sus extremidades inferiores. Esto genera presión constante en áreas vulnerables, como la región sacra, lo que lleva al desarrollo de UPP. Además, la incontinencia urinaria contribuye a la aparición de estas úlceras debido a la exposición constante a la humedad. Para esto, proponemos el desarrollo de un dispositivo preventivo basado en robótica blanda y sensores, compuesto por cinco cojines conectados a un monitor, con un sistema neumático para redistribuir las presiones. También incluye sensores de humedad para notificar al personal médico cuando el paciente realiza sus deposiciones. El sistema está diseñado para ser portátil y adaptable a diferentes situaciones, como cuando el paciente está en cama o en una silla de ruedas. Nuestro objetivo es reducir significativamente la incidencia de UPP en pacientes inmovilizados mediante la redistribución automática de la presión y la detección oportuna de la humedad.
>
> En este sentido desarrollaremos un prototipo funcional con los materiales descritos (sensores de presión, humedad y un sistema neumático), luego realizaremos pruebas con modelos simulados (simulando el peso y la postura de un paciente sobre el colchón y evaluando la efectividad de los sensores de presión y humedad), finalmente ajustaremos la programación del sistema para que funcione de manera intuitiva para el personal médico.
> 
# Referencias
* [1]M.V. Godoy Galindo, B. Huamaní Flores, y Y. Musayón Oblitas, “Prevalencia de úlceras por presión en pacientes hospitalizados de un hospital de Lima” Enferm. Herediana, Vol. 13, pp. 20-27, Junio 2020 https://revistas.upch.edu.pe/index.php/RENH/article/view/4146/4683
* [2]R. Jimenez, “Guía de práctica clínica para el diagnóstico y el manejo de úlceras por presión”, Lima, Perú 2021 https://cdn.www.gob.pe/uploads/document/file/5410459/4838497-guia-de-practica-clinica-para-el-diagnostico-y-manejo-de-ulceras-por-presion.pdf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
* [3]D. Belorwitz. “UpToDate”. Evidence-based Clinical Solutions for Healthcare | UpToDate | Wolters Kluwer. Accedido el 17 de septiembre de 2024. [En línea]. Disponible: https://www.uptodate.com/contents/epidemiology-pathogenesis-and-risk-assessment-of-pressure-induced-skin-and-soft-tissue-injury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
* [4]M. V. Godoy Galindo, B. Huamaní Flores, y Y. Musayón-Oblitas, «Prevalencia de Úlcera por Presión en Pacientes Hospitalizados de un Hospital de Lima», Rev enferm Herediana., vol. 13, pp. 20–27, mar. 20
* [5] D. Belorwitz. “UpToDate”. Evidence-based Clinical Solutions for Healthcare | UpToDate | Wolters Kluwer. Accedido el 17 de septiembre de 2024. [En línea]. Disponible: https://www.uptodate.com/contents/clinical-staging-and-general-management-of-pressure-induced-skin-and-soft-tissue-injury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
* [6]Rehabmart, “Domus Auto Alternating Pressure Mattress”, [En línea]. Disponible en:https://www.rehabmart.com/product/domus-auto-alternating-pressure-mattress-50072.html. [Accedido: 1-Sep-2024]
* [7]Amazon,”Cojines para úlceras de cama para posicionamiento de glúteos, cojín de presión para úlceras, almohada de alivio de presión en forma de dona, cuña para posición de dormir, cuña después de cirugía”,[En linea].Disponible en:https://www.amazon.com/-/es/Cojines-%C3%BAlceras-posicionamiento-almohada-posici%C3%B3n/dp/B095NWD58C?th=1
* [8]D. B. Drennan, “Métodos inalámbricos de alerta de úlceras por presión y sistemas de los mismos”, Patente Española ES 2926481T3, Oficina Española de Patentes y Marcas, 26 de Octubre,2022.
* [9]  M.V. Godoy Galindo, B. Huamaní Flores, y Y. Musayón Oblitas, “Prevalencia de úlceras por presión en pacientes hospitalizados de un hospital de Lima” Enferm. Herediana, Vol. 13, pp. 20-27, Junio 2020 https://revistas.upch.edu.pe/index.php/RENH/article/view/4146/4683
* [10] J. P. Chacón Mejía y A. E. del Carpio Alosilla. “Indicadores Clínicos-Epidemiológicos asociados a úlceras por presión en un hospital de Lima “Facultad de Medicina Humana URP, vol. 19, pp. 66-74, abril 2019 http://www.scielo.org.pe/pdf/rfmh/v19n2/a07v19n2.pdf

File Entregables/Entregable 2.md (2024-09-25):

# Entregable 2
## Estado del Arte (Contexto Comercial)
> #### Equipos/Dispositivos:
>
> * **Sistema de Colchón de Presión Alternante con Ajuste Automático [1]**
>
> Es un dispositivo avanzado diseñado para prevenir y tratar úlceras por presión en pacientes que necesitan estar en cama durante periodos prolongados.
>
> Especificaciones del producto:
>
> Dimensiones: 210.2 cm (L) x 89.92 cm (W) x 20.32 (H)
>
> Peso:6,89 kg
>
> Resistencias de peso: hasta 200 kg
>
>  <p align="center" >
>
>  * **Sistema de Compresión de Dos Capas con Almacenamiento 3M™ Coban™, 2094N, 8/Caja [2]** 
>
>   Diseñado para mejorar el retorno venoso y linfático en el tratamiento de úlceras venosas. 
>
>   Especificaciones: Ancho de la capa de comodidad (sistema métrico): 10 centímetros lineales
>   
>   Condición: Cuidado de las Heridas
> 
>   Departamento: Cuidado de las Heridas
>
>   Número de Catálogo: 2094N
>
>   Tipo Condición Para El Cuidado de Heridas:Úlcera venosa de las piernas
>
>   Tipo de Producto: Vendajes de compresión
>
>   Longitud de la capa de comodidad (sistema métrico): 2.7 Metros
> 
>   Hipoalergénico: Si
>
>   Ancho de la capa de compresión (sistema métrico):10 centímetros lineales
>
>  <p align="center" >
>
> * **Cojines para úlceras de cama para posicionamiento de glúteos, cojín de presión para úlceras, almohada de alivio de presión en forma de dona, cuña para posición de dormir, cuña después de cirugía [3]**
>
>   Marca: AOSSA
>
>   Características especiales: Premium
>
>   Color: Negro
>
>   Material de relleno: Poliéster
>
>   Forma: Cuña
>
>  <p align="center" >
> 
> #### Patentes
>
>  * **ES2926481T3 – Métodos inalámbricos de alerta de úlceras por presión y sistemas de los mismos [4]**
>    
>  Fecha de Publicación: 26 de octubre de 2022
>
>  Lugar de Origen: España
>
>  La patente describe un sistema avanzado de monitorización y alerta para prevenir el desarrollo de las úlceras por presión en pacientes inmovilizados o con movilidad reducida.
>
>   El sistema en sí se basa en la detección de la presión ejercida sobre tejidos blandos durante un periodo prolongado, alertando al paciente o al cuidador para intervenir antes de que se produzcan daños significativos en los tejidos.
>
>    **Componentes claves del sistema** 
>
>  <p align="center">
>
>  **Unidades de detección (14):** Estas son las unidades de detección, que están equipadas con sensores capaces de generar salidas eléctricas que corresponden a la presión detectada en la superficie del cuerpo del paciente. Estos sensores están diseñados para ser altamente sensibles a presiones relativamente bajas, que son críticas en la formación de Úlceras por presión.
>
>    **Convertidor (12):**  Es el núcleo del sistema de monitorización de presión. Se encarga de recibir las señales inalámbricas generadas por las unidades de detección de presión (14). También procesa estas señales y las transmite a otros dispositivos, como la tableta u ordenador (13) para su visualización y análisis. El convertidor opera con energía de una fuente externa o con una batería interna, y está diseñado para manejar múltiples señales de sensores de manera eficiente.
>
>    **Ordenador tipo tableta (13):**  Actúa como interfaz principal para el usuario. Recibe los datos del convertidor (12) y muestra información crucial sobre la presión en los tejidos del paciente en tiempo real. La pantalla (26) permite a los usuarios configurar el sistema, ver las alarmas y monitorizar el estado del paciente. El software de la tableta está diseñado para interactuar con el convertidor, mostrando detalles como el progreso del tiempo y los umbrales de presión superados.
>
>    **Luces Led (16):** Las luces LED en el convertidor sirven para indicar el estado de cada una de las unidades de detección de presión (14). Estas luces se encienden cuando las unidades de detección están activas y en funcionamiento. Además de mostrar que las unidades están activas, las luces LED también alertan sobre cualquier fallo en las unidades de detección, como problemas con la batería. Estas luces permiten al cuidador identificar rápidamente cualquier problema técnico que pueda afectar la eficacia del sistema de monitorización.
>
>    **Luz de Advertencia LED (18):** Esta luz LED adicional está específicamente diseñada para advertir sobre fallos en la batería del convertidor. Si la batería del convertidor (12) se agota o presenta algún fallo, esta luz se encenderá para alertar al usuario. 
>
>   <p align="center" >
>
> 
> * **ES2967292T3-Sistema de vendaje con propiedades mejoradas para uso médico [5]**
>
>    Fecha de publicación: 29 de abril del 2024
>
>    Lugar de Origen: España
>
>   La patente describe un vendaje innovador diseñado para mejorar la protección, el soporte y la curación de heridas. Este vendaje está compuesto por materiales avanzados que permiten una mejor absorción de líquidos, una mayor transpirabilidad, y una mejor adaptación a las formas del cuerpo, lo que contribuye a acelerar el proceso de curación y reducir las complicaciones.
>
>    **Componentes y Funcionalidad del Sistema:**
> <p align="center" >
>   
>   **Capa contacto con la piel (100):** Esta capa es la primera capa que entra en contacto con la piel del paciente. Está diseñada para ser suave y no adherente para evitar que el vendaje se adhiera a la herida o a la piel dañada. El material es transpirable, que mantiene el paso del aire mientras mantiene la humedad adecuada en la herida.
>
>   **Capa Absorbente (102,104):** Estas capas están diseñadas para absorber el exudado de la herida, manteniendo la herida seca y promoviendo un ambiente óptimo para la curación. También juegan un papel crucial en la distribución de la presión aplicada sobre la piel, evitando que se concentre en un solo punto. Usualmente estas capas están hechas de un material altamente absorbente como la espuma de poliuretano.
>
>    **Capas de Distribución de Presión (105,109,113):** Distribuye la presión ejercida sobre la herida a través de una superficie mayor, reduciendo la presión en áreas específicas. Esto es esencial para prevenir la formación de Úlceras por presión en pacientes que están inmóviles por largos periodos. Esta capa está hecha de un material elástico y comprensible, que permite la redistribución de la presión.
>
>   **Capa Externa Protectora (107,112):** La capa externa protege las capas internas del vendaje de contaminantes externos, como bacterias y líquidos, mientras permite la transpiración para mantener la piel seca y saludable. Suele ser resistente al agua pero permeable al vapor, como los materiales tipo membrana.
>
> 
>  * **ES2769298T3- Mejoras significativas en los sistemas de terapia de heridas por presión negativa, enfocándose en la comodidad  y el tratamiento del paciente y la facilidad de uso del sistema. [6]**
>
> La figura 2 ilustra una realización de un sistema de tratamiento de herida por presión negativa que emplea un apósito de herida que puede absorber y almacenar exudado de herida y un adaptador de succión flexible; La figura 2 ilustra una realización de un sistema de tratamiento de herida por presión negativa 5501 que emplea un apósito de herida 5500 conjuntamente con un adaptador de succión flexible 5512. El apósito de herida 5500 puede ser similar a los apósitos ilustrados en las figuras 1A-B. Aquí, el adaptador de succión flexible 5512 puede comprender un puente 5502 que tiene un extremo proximal 5503 y un extremo distal 5505 y un aplicador 5504 en el extremo distal 5505 del puente 5502. Preferiblemente en el extremo proximal 5503 del puente 5502 se dispone un conector 5504. Con el sistema 5501 se puede proporcionar un capuchón 5536 (y en algunos casos, como se ilustra,se puede conectar al conector 5504). El capuchón 5536 puede ser útil para que fuguen fluidos fuera del extremo proximal 5503. El sistema 5501 puede incluir una fuente de presión negativa tal como una bomba o unidad de presión negativa 5534 que pueda suministrar presión negativa. La bomba preferiblemente también comprende un bote u otro recipiente para el almacenamiento de exudados de herida y otros fluidos que pueden ser retirados de la herida. En algunas realizaciones, esta bomba 5534 puede ser una bomba PICO™, como la vendida por Smith & Nephew. La bomba 5534 se puede conectar al conector 5504 por medio de un tubo 5540. En uso, el apósito 5500 se coloca sobre una herida preparada adecuadamente, que en algunos casos puede ser rellenada con un material de relleno de herida tal como espuma o gasa. Posteriormente, con la bomba 5534 conectada por medio del tubo 5540 al conector 5504, la bomba es activada, suministrando de ese modo presión negativa a la herida. La aplicación de presión negativa puede ser aplicada hasta que se logra un nivel de curación deseado de la herida 5530.
>
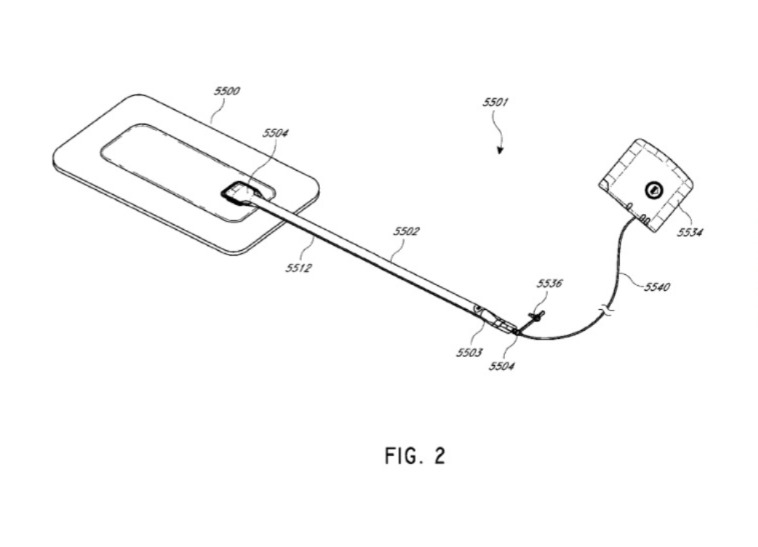
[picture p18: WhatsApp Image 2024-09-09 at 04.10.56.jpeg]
> <p align="center" >
>
> La figura B1 ilustra una realización de un sistema de tratamiento de herida;La figura B1 ilustra una realización de un sistema de tratamiento de heridas por TNP B100 que comprende un apósito de herida B110 en combinación con una bomba B150. Como se ha indicado anteriormente, el apósito de herida B110 puede ser cualquier realización de apósito de herida descrita en esta memoria que incluye sin limitación realización de apósito o tiene cualquier combinación de características de cualquier número de realizaciones de apósitos de herida descritas en esta memoria. Aquí, el apósito B110 se puede colocar sobre una herida como se describe anteriormente, y un conducto B130 puede conectarse entonces al adaptador de paso B120, aunque en algunas realizaciones el apósito B101 puede estar provisto con por lo menos una parte del conducto B130 preconectada al adaptador de paso B120. Preferiblemente, el apósito B110 se proporciona como un único artículo con todos elementos de apósito de herida (incluido el adaptador de paso B120) preconectados e integrados en una única unidad. El apósito de herida B110 puede conectarse entonces, a través del conducto B130, a una fuente de presión negativa tal como la bomba B150. Preferiblemente, la bomba B150 es miniaturizada y portátil, aunque con el apósito B110 también se pueden usar bombas convencionales más grandes. En algunas realizaciones, la bomba B150 se puede conectar o montar sobre o adyacente al apósito B110. También puede proporcionarse un conector B140 para permitir que el conducto B130 que lleva el apósito de herida B110 sea desconectado de la bomba, que puede ser útil por ejemplo durante los cambios de apósito.
>
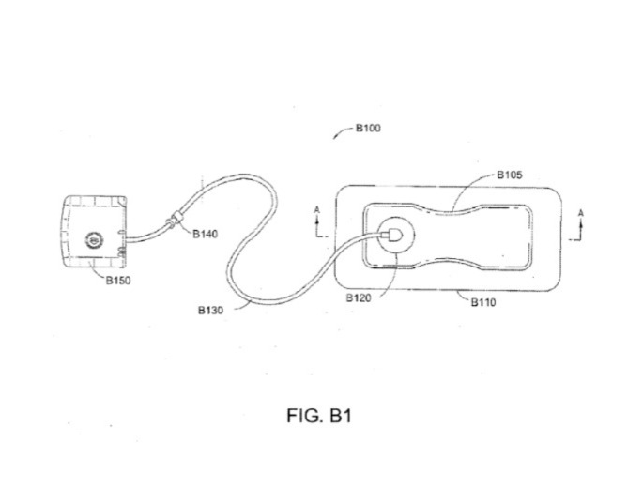
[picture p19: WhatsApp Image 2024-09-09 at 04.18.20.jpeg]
> <p align="center" >

## Lista de requerimientos
> ### Funcionales
> * Otorgar autonomía al paciente para realizar los cambios posturales.
> * Sistema operativo de ayuda al paciente, detectando su intención de movimiento.
> * Sistema neumático activo según los cambios posturales, buscando aliviar presiones en puntos determinados
> * Sistema neumático compuesto por infladores, en el muslo, se activan para dar apoyo en los cambios posturales 

> ### No funcionales
> * Dispositivo de bajo costo
> * Equipo no invasivo
> * Dispositivo flexible y adaptable al paciente
> * Material blando, adaptable, hipoalérgico y antitranspirante.
> * Facilidad de colocar y retirar el dispositivo

## Planteamiento de solución
> Dispositivo de prevención de úlceras por presión. La idea solución consiste en abrazaderas inflables ubicadas en los muslos las cuales están divididas por secciones, donde se infle la sección más provechosa para el cambio postural que se desee realizar y para evitar los roces entre las rodillas. Además la rotación del torso con las piernas se realizará mediante el impulso que brindará el inflable según el comando señalado en el control remoto y el impulso del paciente al estar inclinado. Todo el dispositivo se realizará de tal modo que sea fácil de retirar y colocar para dar paso a la higiene necesaria y cambios de ropa en la parte inferior del cuerpo.

## Bibliografía 
* [1] Rehabmart, “Domus Auto Alternating Pressure Mattress”, [En línea]. Disponible en:https://www.rehabmart.com/product/domus-auto-alternating-pressure-mattress-50072.html. [Accedido: 1-Sep-2024]
* [2] Smchile,“Sistema de Compresión de Dos Capas con Almacenamiento 3M™ Coban™, 2094N, 8/Caja”  ,[En linea].Disponible en:https://www.3mchile.cl/3M/es_CL/p/d/b00036433/
* [3] Amazon,”Cojines para úlceras de cama para posicionamiento de glúteos, cojín de presión para úlceras, almohada de alivio de presión en forma de dona, cuña para posición de dormir, cuña después de cirugía”,[En linea].Disponible  en:https://www.amazon.com/-/es/Cojines-%C3%BAlceras-posicionamiento-almohada-posici%C3%B3n/dp/B095NWD58C?th=1
* [4] D. B. Drennan, “Métodos inalámbricos de alerta de úlceras por presión y sistemas de los mismos”, Patente Española ES 2926481T3, Oficina Española de Patentes y Marcas, 26 de Octubre,2022.
* [5] Rodzewicz,Patrick; Márlind,Linda;Hansson,Deniis;Grou,Anna;Jakobsson,Conny y Lancon,Océane “Vendaje Médico”, Oficina Española de Patentes y Marcas,29 de abril, 2024.
* [6] ALLEN, JULIE;ASKEM, BEN, ALAN; COLLINSON, SARAH, JENNY; GOWANS, PHILIP;MEHTA, STEVEN, CARL; NICOLINI, DEREK y ZAGRABSKI, CAROL,”Aparatos para terapia de heridas por presión negativa”.España.Patente 2 769 298 Jun.25,2020

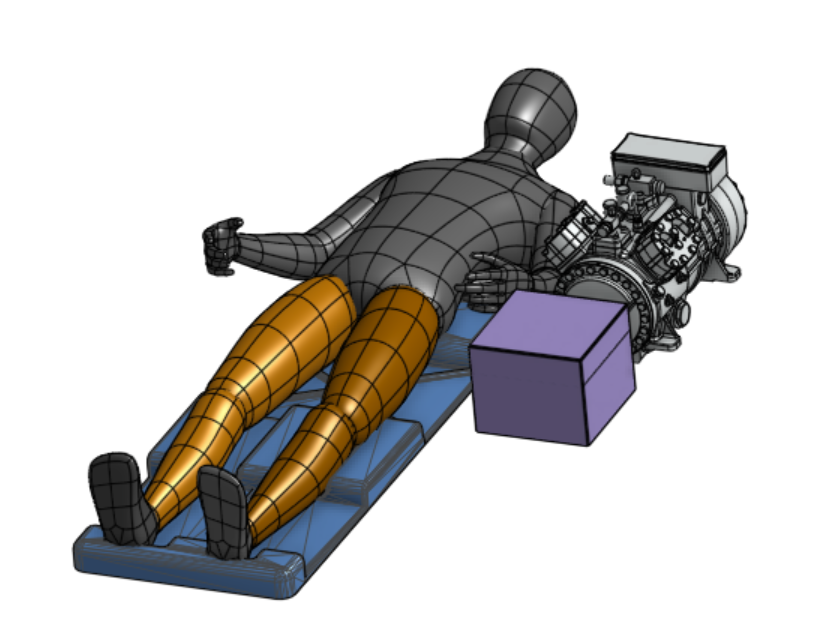
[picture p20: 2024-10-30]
Modelo 3D/Posición frontal.png

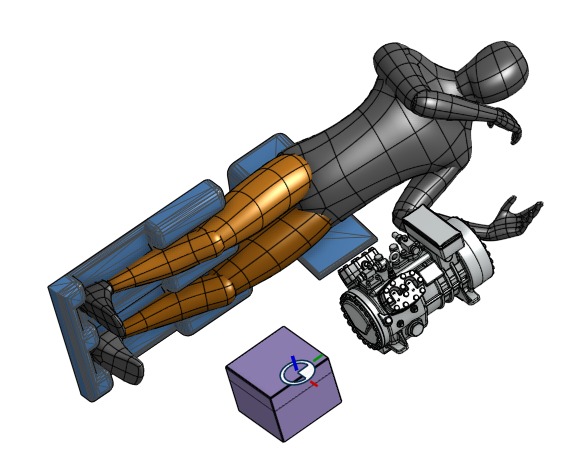
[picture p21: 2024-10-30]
Modelo 3D/Costado.jpeg

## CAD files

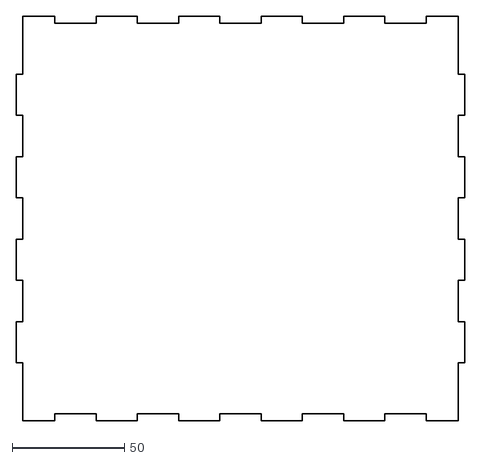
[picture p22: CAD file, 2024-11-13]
Hardware/Sistema electrónico/Right - DXF.dxf
200.0 x 180.0

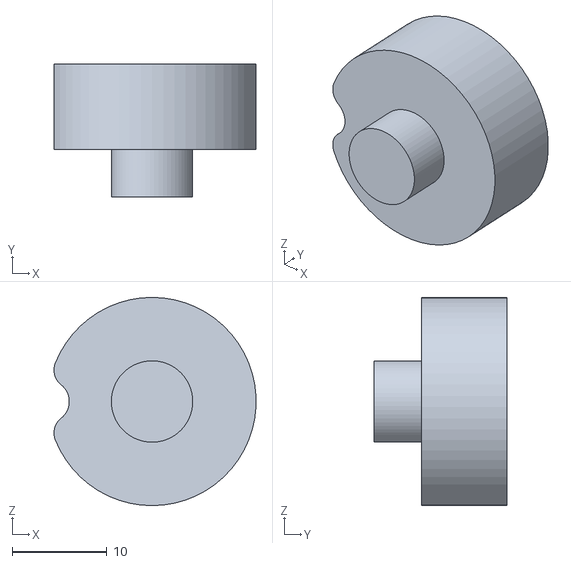
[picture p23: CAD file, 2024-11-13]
Hardware/Válvulas/CABEZA MICROSERVO.stl
21.3 x 14.0 x 22.0

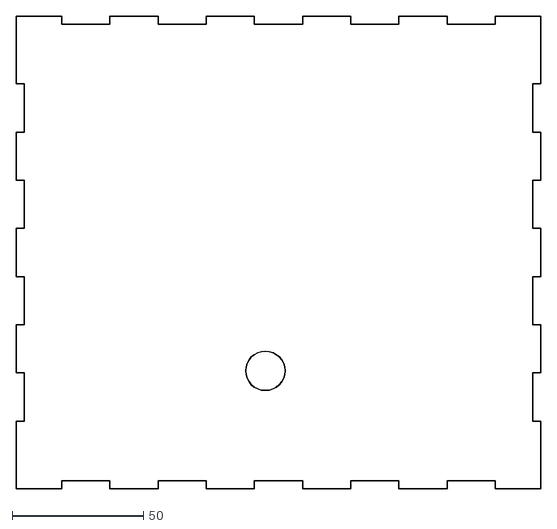
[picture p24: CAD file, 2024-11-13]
Hardware/Sistema electrónico/Back - DXF.dxf
200.0 x 180.0

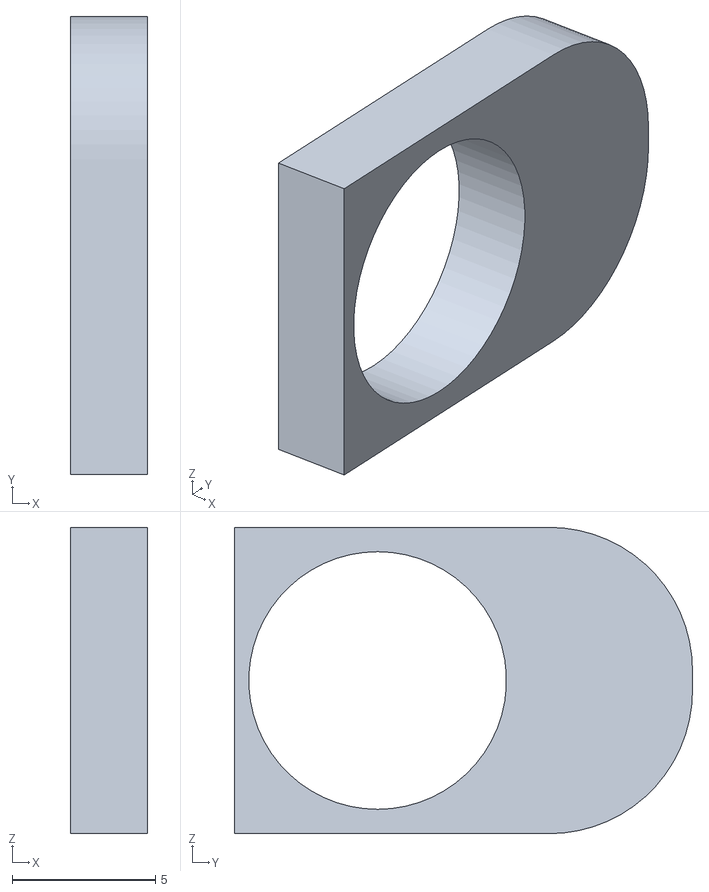
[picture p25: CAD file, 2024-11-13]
Hardware/Válvulas/PIEZA VALVULA MICRO.stl
2.70 x 16.0 x 10.7

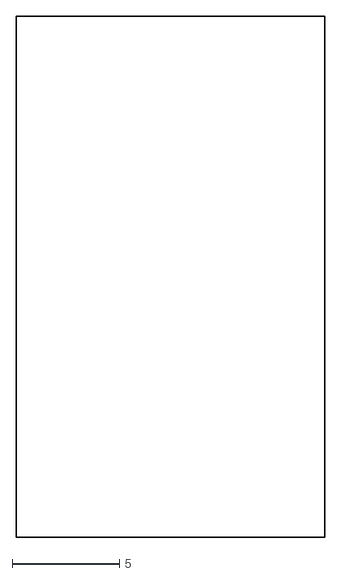
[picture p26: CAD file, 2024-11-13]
Hardware/Sistema electrónico/Soporte Middle - DXF.dxf
14.4 x 24.3

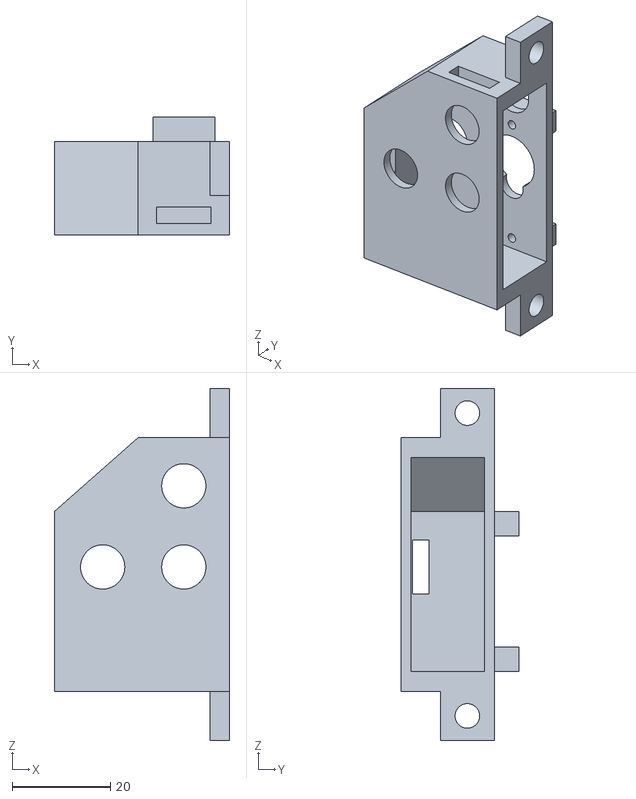
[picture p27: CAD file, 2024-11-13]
Hardware/Válvulas/VÁLVULA MICROSERVO.stl
35.6 x 24.0 x 71.6

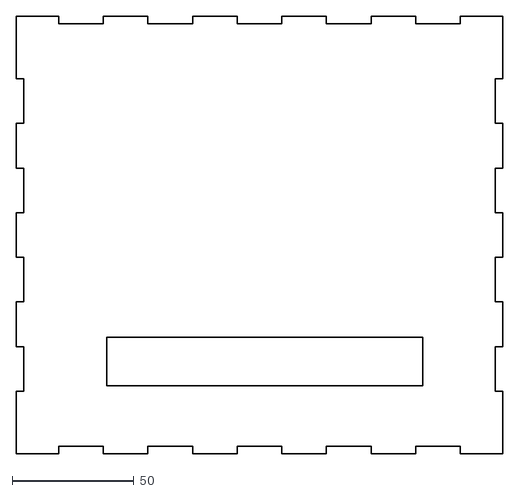
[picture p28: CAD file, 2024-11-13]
Hardware/Sistema electrónico/Front - DXF.dxf
200.0 x 180.0

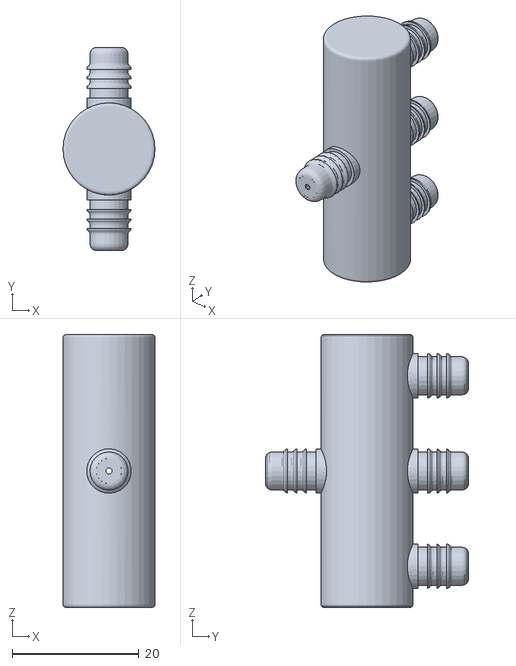
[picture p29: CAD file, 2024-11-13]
Hardware/Válvulas/válvula cuatro entradas.stl
14.5 x 32.0 x 43.0

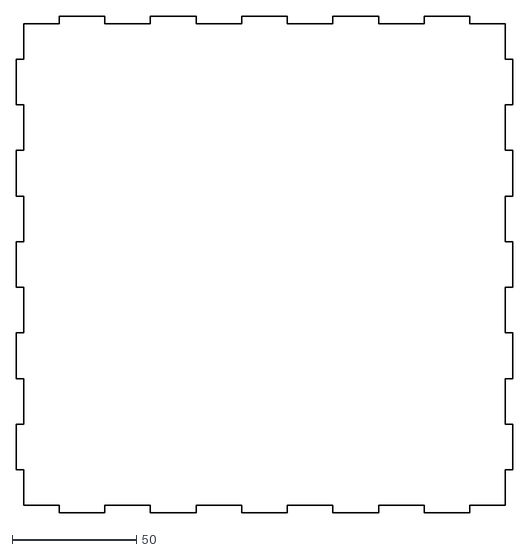
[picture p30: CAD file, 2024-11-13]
Hardware/Sistema electrónico/Top - DXF.dxf
200.0 x 200.0

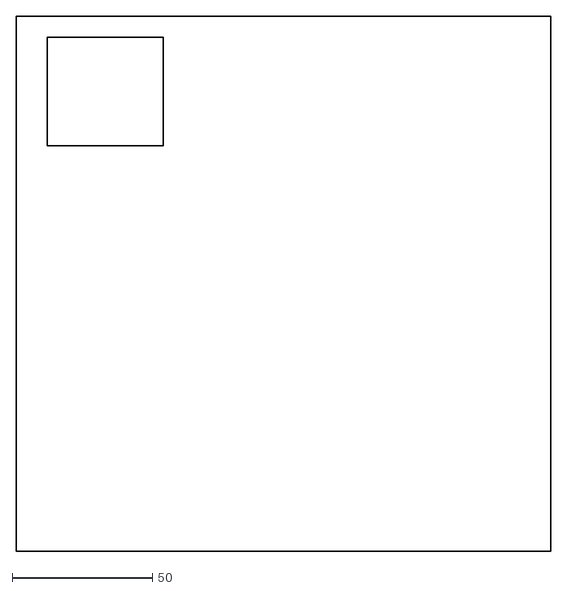
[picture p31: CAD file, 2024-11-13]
Hardware/Sistema electrónico/Middle - DXF.dxf
190.8 x 190.8

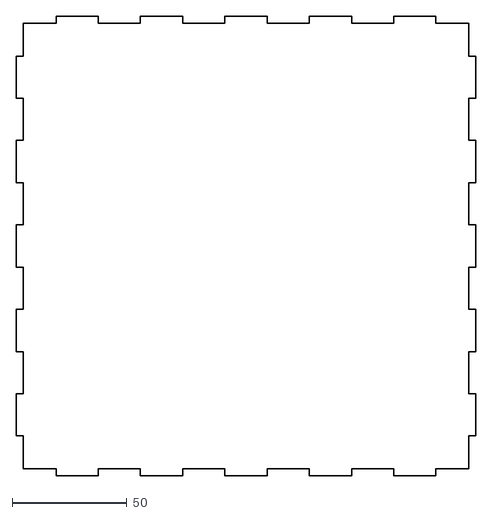
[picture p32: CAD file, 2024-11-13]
Hardware/Sistema electrónico/Bottom - DXF.dxf
200.0 x 200.0

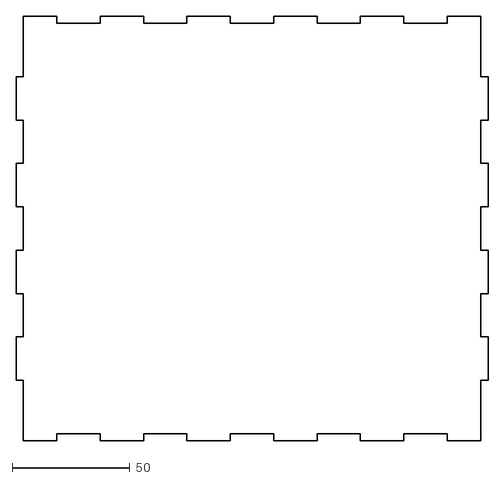
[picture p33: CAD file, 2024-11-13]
Hardware/Sistema electrónico/Left - DXF.dxf
200.0 x 180.0

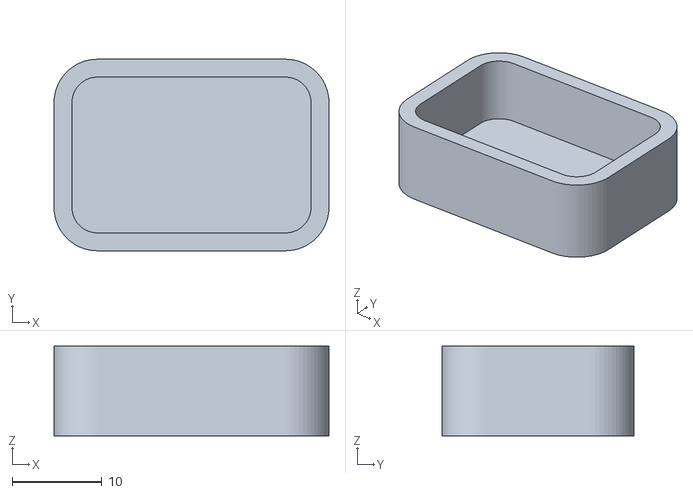
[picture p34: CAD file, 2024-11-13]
Hardware/Sistema electrónico/bateria.stl
30.7 x 21.4 x 10.0

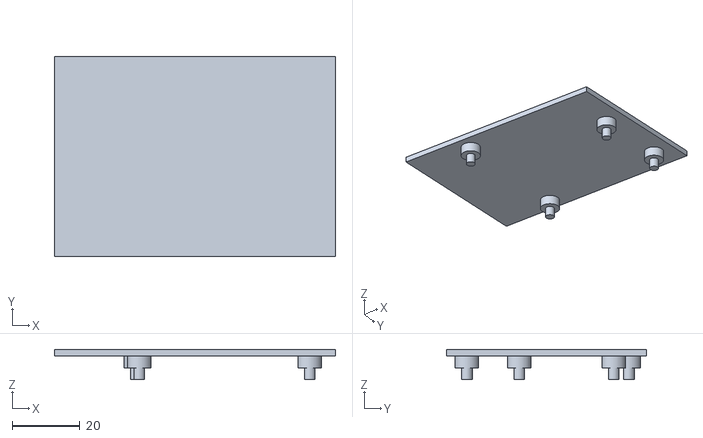
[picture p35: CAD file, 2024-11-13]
Hardware/Sistema electrónico/Soporte Aurduino.stl
83.3 x 59.2 x 9.00

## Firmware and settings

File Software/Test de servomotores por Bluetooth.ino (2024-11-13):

#include <SoftwareSerial.h>
#include <Servo.h>

// Definir los pines RX y TX para el Bluetooth
SoftwareSerial bluetooth(2,3); // RX en pin 2, TX en pin 3 (ajustar según la configuración)

// Crear tres objetos Servo para cada motor
Servo servo1;
Servo servo2;
Servo servo3;

// Variables para rastrear la posición actual de cada servomotor
int posServo1 = 0;
int posServo2 = 0;
int posServo3 = 0;

void setup() {
  Serial.begin(9600);
  bluetooth.begin(9600);
  Serial.println("Esperando comandos desde el Bluetooth...");

  // Adjuntar cada servomotor a un pin PWM del Arduino
  servo1.attach(9);  // Pin 9 para el servo 1
  servo2.attach(10); // Pin 10 para el servo 2
  servo3.attach(11); // Pin 11 para el servo 3
}

void loop() {
  if (bluetooth.available()) { 
    char command = bluetooth.read(); // Leer comando del Bluetooth
    Serial.print("Comando recibido: ");
    Serial.println(command);

    // Control para el Servo 1
    if (command == 'a') {
      posServo1 = 180;
      servo1.write(posServo1);  // Gira 180° en sentido antihorario
    } else if (command == 'j') {
      posServo1 = 0;
      servo1.write(posServo1);  // Gira 180° en sentido horario
    }

    // Control para el Servo 2
    else if (command == 's') {
      posServo2 = 180;
      servo2.write(posServo2);  // Gira 180° en sentido antihorario
    } else if (command == 'k') {
      posServo2 = 0;
      servo2.write(posServo2);  // Gira 180° en sentido horario
    }

    // Control para el Servo 3
    else if (command == 'd') {
      posServo3 = 180;
      servo3.write(posServo3);  // Gira 180° en sentido antihorario
    } else if (command == 'l') {
      posServo3 = 0;
      servo3.write(posServo3);  // Gira 180° en sentido horario
    }
  }
}

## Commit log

2024-09-12 Espina de ishikawa
    Mejor diseño
2024-10-30 codigo arduino parte 2
2024-10-30 codigo arduino tercera imagen
